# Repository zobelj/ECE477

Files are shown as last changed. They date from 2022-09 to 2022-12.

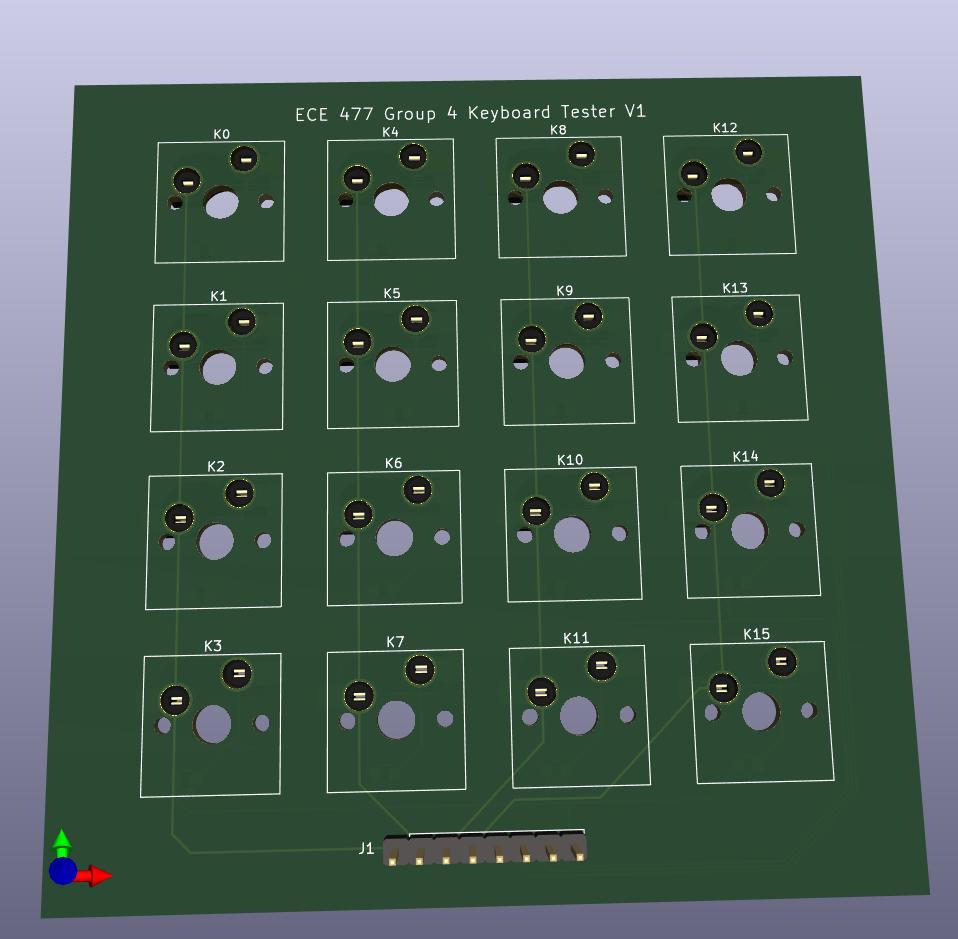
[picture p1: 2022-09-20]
KBT1/renders/KBT1-1.jpg

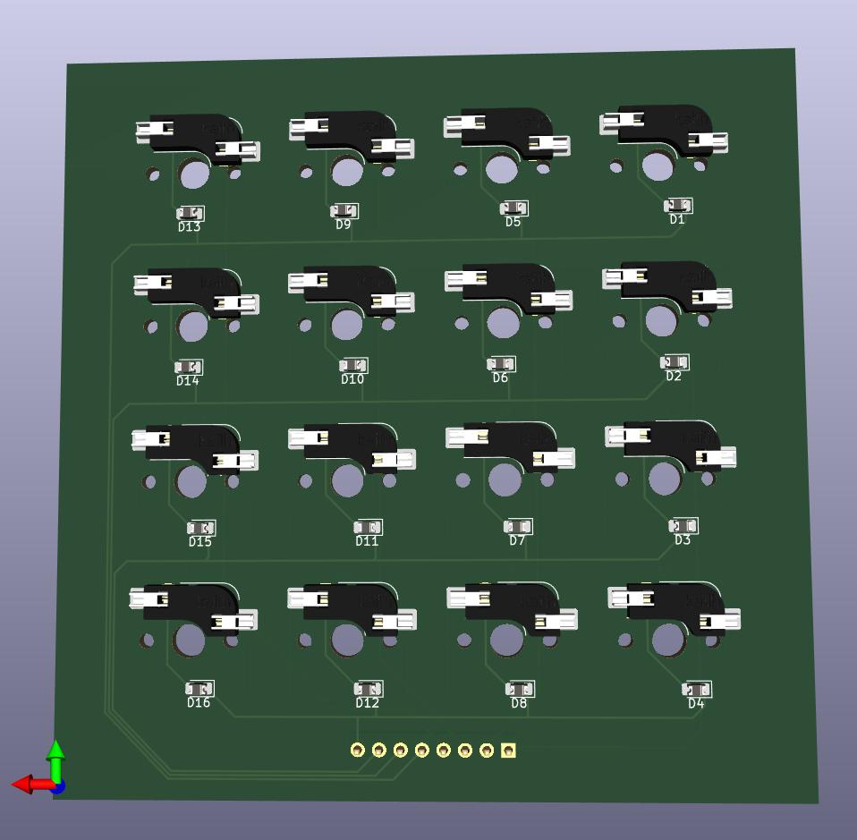
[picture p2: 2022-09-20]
KBT1/renders/KBT1-2.jpg

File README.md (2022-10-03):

# Split USB Keyboard
ECE477 Team 4 github

## Reset source code to work as keyboard
1. Make changes to .ioc file and save it
2. Build the code
3. Delete the Middlewares folder
4. Unzip Middlewares KEYBOARD SETUP.zip and rename the folder to Middlewares (Keep the ziped file here for future use)
5. Build the code (there will likely be errors, if so proceed to step 6)
6. Navigate to Drivers>STM32F4xx_HAL_DRIVER>Src in this directory there will be duplicate files that look like this `...cortex.c` and `...cortext 2.c` or `...cortex 3.c` to fix this delete all of the files that have a number at the end of the file name. This can easily be done in the console/terminal with `rm *2.c` or `rm *3.c`

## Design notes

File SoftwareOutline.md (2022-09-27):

# Software Outline

This file is meant to serve as a general outline of the software running on the microcontrollers.

In its current state, only an outline of the keyboard input is included but will be updated to describe LCD functions, etc.

NOTE: When wiring the 4x4 test PCB, the columns are the left 4 pins and the rows are the right 4 pins. The columns should be pulled high.

## Keyboard Input

---

### Preprocessing Overview
Some global variables will be set up before the keyboard is ready to use.

Tasks:
- set `rows` to be outputs, initialize all to low (eg. PA0-PA3)
- set `cols` to be inputs (eg. PA4-PA7)
- setup timer interrupt
- setup pins
- ...

Global variables:
- `queue` : array that holds the keypresses to be sent 
- `queue_index` : the index of the next available space in the queue
- ...

---

### Timer Interrupt Overview
- A timer `TIMx` will be set to interrupt the process at a  frequency of 10kHz (?)
- `TIMx_IRQHandler()` will do the following:
  - Acknowledge the interrupt
  - Check for columns that are activated (`get_cols()`)
  - Update the `queue` variable with any keys that were pressed between `send_data()` calls
  - Change the row currently set (`set_rows()`)
- `send_data()` sends the queue to the host PC at a frequency of 1000Hz (polling rate)
  - resets `queue`, prepares for next packet
- 

---

### Functions to Implement
- `get_key()`
  - waits for the interrupt to update the queue
  - converts the row-column value in queue to a key (switch case)
  - returns the key being pressed
  - *Is this useful for our keyboard? I don't think we should have a `get_key()` function*
  - *This funcitonality should probably exist in the `send_data()` function or in `main()`*
- `TIMx_IRQHandler()`
  - runs `get_cols()`
  - figures out what key is being pressed
  - runs `set_rows()` to change active row for the next interrupt
- `TIMx_setup()`
  - initializes the timer frequency
  - enables the timer
- `setup_pins()`
  - initialize pins for rows and columns
  - maybe initialize other necessary pins (LCDs, LEDs, etc.)
- `get_cols()`
  - returns the values of the column inputs as a 4-bit number
  - eg. `0010` indicates that columns 0, 2, and 3 are low and column 1 is high
- `set_rows()`
  - one active row at a time
  - changes the active row to the next row
  - eg. `0001` -> `0010` indicates the active row is changed from row 0 to row 1
- `update_queue`
  - add new keypresses to the end of the queue
  - these keypresses will be included in the next packet sent to the PC
- `send_data()`
  - send the queue to the host PC
  - clear the queue, reset the queue index

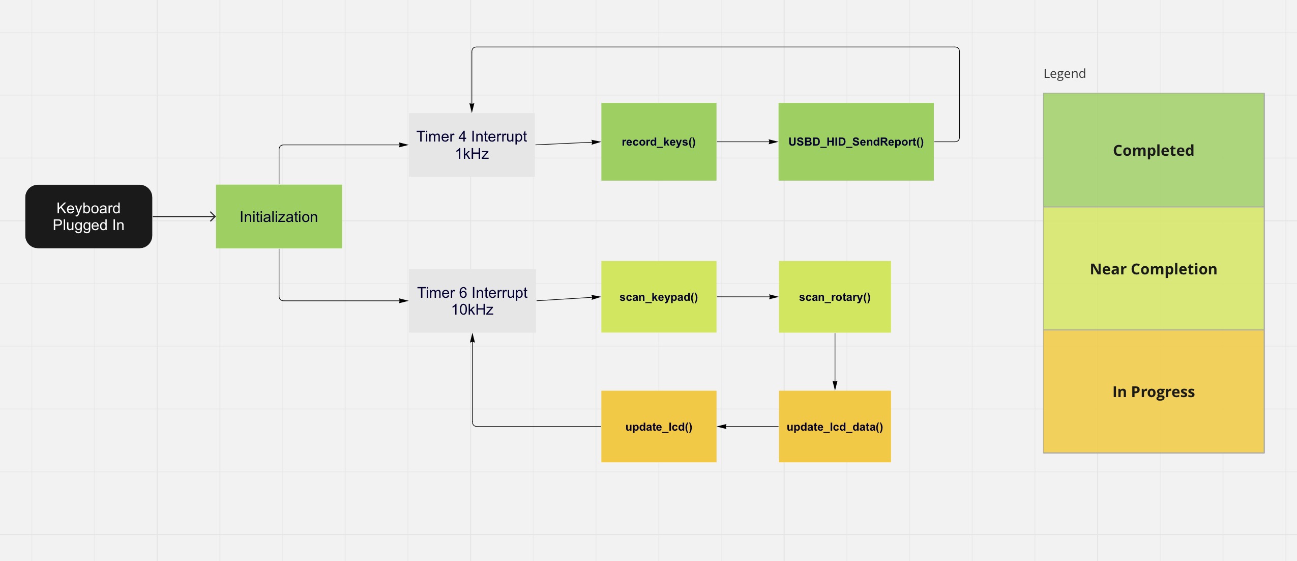
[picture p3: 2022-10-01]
Software_Flowchart.jpg

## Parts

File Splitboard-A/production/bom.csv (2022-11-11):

Designator | Footprint | Quantity | Value | LCSC Part #
C1, C2 | C_0805_2012Metric | 2 | 2u2
C10, C11, C12, C13, C14, C15, C18, C20, C21, C5, C7, C8, C9 | C_0805_2012Metric | 13 | 100nF
C16, C17 | C_0805_2012Metric | 2 | .01uF
C19, C6 | C_0805_2012Metric | 2 | 10uf
C3, C4 | C_0805_2012Metric | 2 | 10u
D1, D10, D11, D12, D13, D14, D15, D16, D17, D18, D19, D2, D20, D21, D22, D23, D24, D25, D26, D27, D28, D29, D3, D30, D31, D32, D33, D34, D35, D36, D37, D38, D4, D5, D6, D7, D8, D9 | D_SOD-123 | 38 | D
D39, D40, D41 | D_SOD-123 | 3 | D_Schottky
FB1 | R_0805_2012Metric | 1 | 100 @ 100 MHz
H1, H2, H3, H4 | MountingHole_2.7mm | 4 | MountingHole
J1 | USB_C_Receptacle_Amphenol_12401548E4-2A | 1 | USB_C_Receptacle_USB2.0
J2 | USB_C_Receptacle_Amphenol_12401548E4-2A | 1 | USB_C_Receptacle
J3 | PinHeader_1x06_P2.54mm_Horizontal | 1 | Conn_01x06
K1, K10, K11, K12, K13, K14, K15, K16, K17, K18, K19, K2, K20, K21, K22, K23, K24, K25, K26, K27, K28, K29, K3, K30, K31, K32, K33, K34, K35, K36, K37, K38, K4, K5, K6, K7, K8, K9 | SW_Hotswap_Kailh_MX_plated | 38 | KEYSW
R1, R2 | R_0805_2012Metric | 2 | 5K1
R10, R11, R12, R13, R14, R15, R4, R5, R6, R7, R8, R9 | R_0805_2012Metric | 12 | 10k
R16, R17, R18, R19, R20, R21, R22, R23, R24, R25, R26, R27, R28, R29, R3, R30, R31, R32, R33, R34, R35, R36, R37 | R_0805_2012Metric | 23 | 20
R38, R39 | R_0805_2012Metric | 2 | 4k7
SW1 | RotaryEncoder_Alps_EC11E-Switch_Vertical_H20mm | 1 | RotaryEncoder
SW2 | SW_PUSH_6mm | 1 | SW_Push
U1 | SIT2024BA-S2-33E-8.000000G | 1 | SIT2024BA-S2-33E-8.000000G
U2 | CR2013-MI2120 | 1 | CR2013-MI2120
U3 | LQFP-100_14x14mm_P0.5mm | 1 | STM32F407VGTx
U4 | SOT-223-3_TabPin2 | 1 | AMS1117-3.3
U5 | USBUF02W6 | 1 | USBUF02W6

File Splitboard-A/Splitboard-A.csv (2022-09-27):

Source: | /home/smol/Projects/ECE477/Splitboard-A/Splitboard-A.kicad_sch
Date: | Thu 22 Sep 2022 04:38:41 PM EDT
Tool: | Eeschema 6.0.7-f9a2dced07~116~ubuntu20.04.1
Generator: | /usr/share/kicad/plugins/bom_csv_grouped_by_value.py
Component Count: | 96
Individual Components:
Item | Qty | Reference(s) | Value | LibPart | Footprint | Datasheet
 |  | C2 | 10u | Device:C | Capacitor_SMD:C_0805_2012Metric | ~
 |  | C3 | 0.1uF | Device:C | Resistor_SMD:R_0805_2012Metric | ~
 |  | C4 | 10u | Device:C | Capacitor_SMD:C_0805_2012Metric | ~
 |  | D1 | D | KBT1-rescue:D-Device | Diode_SMD:D_SOD-123
 |  | D2 | D | KBT1-rescue:D-Device | Diode_SMD:D_SOD-123
 |  | D3 | D | KBT1-rescue:D-Device | Diode_SMD:D_SOD-123
 |  | D4 | D | KBT1-rescue:D-Device | Diode_SMD:D_SOD-123
 |  | D5 | D | KBT1-rescue:D-Device | Diode_SMD:D_SOD-123
 |  | D6 | D | KBT1-rescue:D-Device | Diode_SMD:D_SOD-123
 |  | D7 | D | KBT1-rescue:D-Device | Diode_SMD:D_SOD-123
 |  | D8 | D | KBT1-rescue:D-Device | Diode_SMD:D_SOD-123
 |  | D9 | D | KBT1-rescue:D-Device | Diode_SMD:D_SOD-123
 |  | D10 | D | KBT1-rescue:D-Device | Diode_SMD:D_SOD-123
 |  | D11 | D | KBT1-rescue:D-Device | Diode_SMD:D_SOD-123
 |  | D12 | D | KBT1-rescue:D-Device | Diode_SMD:D_SOD-123
 |  | D13 | D | KBT1-rescue:D-Device | Diode_SMD:D_SOD-123
 |  | D14 | D | KBT1-rescue:D-Device | Diode_SMD:D_SOD-123
 |  | D15 | D | KBT1-rescue:D-Device | Diode_SMD:D_SOD-123
 |  | D16 | D | KBT1-rescue:D-Device | Diode_SMD:D_SOD-123
 |  | D17 | D | KBT1-rescue:D-Device | Diode_SMD:D_SOD-123
 |  | D18 | D | KBT1-rescue:D-Device | Diode_SMD:D_SOD-123
 |  | D19 | D | KBT1-rescue:D-Device | Diode_SMD:D_SOD-123
 |  | D20 | D | KBT1-rescue:D-Device | Diode_SMD:D_SOD-123
 |  | D21 | D | KBT1-rescue:D-Device | Diode_SMD:D_SOD-123
 |  | D22 | D | KBT1-rescue:D-Device | Diode_SMD:D_SOD-123
 |  | D23 | D | KBT1-rescue:D-Device | Diode_SMD:D_SOD-123
 |  | D24 | D | KBT1-rescue:D-Device | Diode_SMD:D_SOD-123
 |  | D25 | D | KBT1-rescue:D-Device | Diode_SMD:D_SOD-123
 |  | D26 | D | KBT1-rescue:D-Device | Diode_SMD:D_SOD-123
 |  | D27 | D | KBT1-rescue:D-Device | Diode_SMD:D_SOD-123
 |  | D28 | D | KBT1-rescue:D-Device | Diode_SMD:D_SOD-123
 |  | D29 | D | KBT1-rescue:D-Device | Diode_SMD:D_SOD-123
 |  | D30 | D | KBT1-rescue:D-Device | Diode_SMD:D_SOD-123
 |  | D31 | D | KBT1-rescue:D-Device | Diode_SMD:D_SOD-123
 |  | D32 | D | KBT1-rescue:D-Device | Diode_SMD:D_SOD-123
 |  | D33 | D | KBT1-rescue:D-Device | Diode_SMD:D_SOD-123
 |  | D34 | D | KBT1-rescue:D-Device | Diode_SMD:D_SOD-123
 |  | D35 | D | KBT1-rescue:D-Device | Diode_SMD:D_SOD-123
 |  | D36 | D | KBT1-rescue:D-Device | Diode_SMD:D_SOD-123
 |  | D37 | D | KBT1-rescue:D-Device | Diode_SMD:D_SOD-123
 |  | D38 | D | KBT1-rescue:D-Device | Diode_SMD:D_SOD-123
 |  | D39 | D_Schottky | Device:D_Schottky |  | ~
 |  | D40 | D_Schottky | Device:D_Schottky |  | ~
 |  | D41 | D_Schottky | Device:D_Schottky |  | ~
 |  | F1 | 500mA | Device:Fuse |  | ~
 |  | FB1 | 100 @ 100 MHz | Device:FerriteBead |  | ~
 |  | H1 | MountingHole | Mechanical:MountingHole | MountingHole:MountingHole_2.7mm | ~
 |  | H2 | MountingHole | Mechanical:MountingHole | MountingHole:MountingHole_2.7mm | ~
 |  | H3 | MountingHole | Mechanical:MountingHole | MountingHole:MountingHole_2.7mm | ~
 |  | H4 | MountingHole | Mechanical:MountingHole | MountingHole:MountingHole_2.7mm | ~
 |  | J1 | USB_C_Receptacle | Connector:USB_C_Receptacle | Connector_USB:USB_C_Receptacle_Amphenol_12401548E4-2A_CircularHoles | https://www.usb.org/sites/default/files/documents/usb_type-c.zip
 |  | J2 | USB_C_Receptacle_USB2.0 | Connector:USB_C_Receptacle_USB2.0 | Connector_USB:USB_C_Receptacle_Amphenol_12401548E4-2A_CircularHoles | https://www.usb.org/sites/default/files/documents/usb_type-c.zip
 |  | K1 | KEYSW | KBT1-rescue:KEYSW-keyboard_parts | 6:SW_Hotswap_Kailh_MX_plated
 |  | K2 | KEYSW | KBT1-rescue:KEYSW-keyboard_parts | 6:SW_Hotswap_Kailh_MX_plated
 |  | K3 | KEYSW | KBT1-rescue:KEYSW-keyboard_parts | 6:SW_Hotswap_Kailh_MX_plated
 |  | K4 | KEYSW | KBT1-rescue:KEYSW-keyboard_parts | 6:SW_Hotswap_Kailh_MX_plated
 |  | K5 | KEYSW | KBT1-rescue:KEYSW-keyboard_parts | 6:SW_Hotswap_Kailh_MX_plated
 |  | K6 | KEYSW | KBT1-rescue:KEYSW-keyboard_parts | 6:SW_Hotswap_Kailh_MX_plated
 |  | K7 | KEYSW | KBT1-rescue:KEYSW-keyboard_parts | 6:SW_Hotswap_Kailh_MX_plated
 |  | K8 | KEYSW | KBT1-rescue:KEYSW-keyboard_parts | 6:SW_Hotswap_Kailh_MX_plated
 |  | K9 | KEYSW | KBT1-rescue:KEYSW-keyboard_parts | 6:SW_Hotswap_Kailh_MX_plated
 |  | K10 | KEYSW | KBT1-rescue:KEYSW-keyboard_parts | 6:SW_Hotswap_Kailh_MX_plated
 |  | K11 | KEYSW | KBT1-rescue:KEYSW-keyboard_parts | 6:SW_Hotswap_Kailh_MX_plated
 |  | K12 | KEYSW | KBT1-rescue:KEYSW-keyboard_parts | 6:SW_Hotswap_Kailh_MX_plated
 |  | K13 | KEYSW | KBT1-rescue:KEYSW-keyboard_parts | 6:SW_Hotswap_Kailh_MX_plated
 |  | K14 | KEYSW | KBT1-rescue:KEYSW-keyboard_parts | 6:SW_Hotswap_Kailh_MX_plated
 |  | K15 | KEYSW | KBT1-rescue:KEYSW-keyboard_parts | 6:SW_Hotswap_Kailh_MX_plated
 |  | K16 | KEYSW | KBT1-rescue:KEYSW-keyboard_parts | 6:SW_Hotswap_Kailh_MX_plated
 |  | K17 | KEYSW | KBT1-rescue:KEYSW-keyboard_parts | 6:SW_Hotswap_Kailh_MX_plated
 |  | K18 | KEYSW | KBT1-rescue:KEYSW-keyboard_parts | 6:SW_Hotswap_Kailh_MX_plated
 |  | K19 | KEYSW | KBT1-rescue:KEYSW-keyboard_parts | 6:SW_Hotswap_Kailh_MX_plated
 |  | K20 | KEYSW | KBT1-rescue:KEYSW-keyboard_parts | 6:SW_Hotswap_Kailh_MX_plated
 |  | K21 | KEYSW | KBT1-rescue:KEYSW-keyboard_parts | 6:SW_Hotswap_Kailh_MX_plated
 |  | K22 | KEYSW | KBT1-rescue:KEYSW-keyboard_parts | 6:SW_Hotswap_Kailh_MX_plated
 |  | K23 | KEYSW | KBT1-rescue:KEYSW-keyboard_parts | 6:SW_Hotswap_Kailh_MX_plated
 |  | K24 | KEYSW | KBT1-rescue:KEYSW-keyboard_parts | 6:SW_Hotswap_Kailh_MX_plated
 |  | K25 | KEYSW | KBT1-rescue:KEYSW-keyboard_parts | 6:SW_Hotswap_Kailh_MX_plated
 |  | K26 | KEYSW | KBT1-rescue:KEYSW-keyboard_parts | 6:SW_Hotswap_Kailh_MX_plated
 |  | K27 | KEYSW | KBT1-rescue:KEYSW-keyboard_parts | 6:SW_Hotswap_Kailh_MX_plated
 |  | K28 | KEYSW | KBT1-rescue:KEYSW-keyboard_parts | 6:SW_Hotswap_Kailh_MX_plated
 |  | K29 | KEYSW | KBT1-rescue:KEYSW-keyboard_parts | 6:SW_Hotswap_Kailh_MX_plated
 |  | K30 | KEYSW | KBT1-rescue:KEYSW-keyboard_parts | 6:SW_Hotswap_Kailh_MX_plated
 |  | K31 | KEYSW | KBT1-rescue:KEYSW-keyboard_parts | 6:SW_Hotswap_Kailh_MX_plated
 |  | K32 | KEYSW | KBT1-rescue:KEYSW-keyboard_parts | 6:SW_Hotswap_Kailh_MX_plated
 |  | K33 | KEYSW | KBT1-rescue:KEYSW-keyboard_parts | 6:SW_Hotswap_Kailh_MX_plated
 |  | K34 | KEYSW | KBT1-rescue:KEYSW-keyboard_parts | 6:SW_Hotswap_Kailh_MX_plated
 |  | K35 | KEYSW | KBT1-rescue:KEYSW-keyboard_parts | 6:SW_Hotswap_Kailh_MX_plated
 |  | K36 | KEYSW | KBT1-rescue:KEYSW-keyboard_parts | 6:SW_Hotswap_Kailh_MX_plated
 |  | K37 | KEYSW | KBT1-rescue:KEYSW-keyboard_parts | 6:SW_Hotswap_Kailh_MX_plated
 |  | K38 | KEYSW | KBT1-rescue:KEYSW-keyboard_parts | 6:SW_Hotswap_Kailh_MX_plated
 |  | R3 | 10K | Device:R | Resistor_SMD:R_0805_2012Metric | ~
 |  | R4 | 100K | Device:R | Resistor_SMD:R_0805_2012Metric | ~
 |  | SW1 | RotaryEncoder | Device:RotaryEncoder | Rotary_Encoder:RotaryEncoder_Alps_EC12E_Vertical_H20mm | ~
 |  | U1 | STM32F407VGTx | MCU_ST_STM32F4:STM32F407VGTx | Package_QFP:LQFP-100_14x14mm_P0.5mm | http://www.st.com/st-web-ui/static/active/en/resource/technical/document/datasheet/DM00037051.pdf
 |  | U2 | AMS1117-3.3 | Regulator_Linear:AMS1117-3.3 | Package_TO_SOT_SMD:SOT-223-3_TabPin2 | http://www.advanced-monolithic.com/pdf/ds1117.pdf
 |  | U3 | CR2013-MI2120 | Driver_Display:CR2013-MI2120 | Display:CR2013-MI2120 | http://pan.baidu.com/s/11Y990
Collated Components:
Item | Qty | Reference(s) | Value | LibPart | Footprint | Datasheet
1 | 2 | C2, C4 | 10u | Device:C | Capacitor_SMD:C_0805_2012Metric | ~
2 | 1 | C3 | 0.1uF | Device:C | Resistor_SMD:R_0805_2012Metric | ~
3 | 38 | D1, D2, D3, D4, D5, D6, D7, D8, D9, D10, D11, D12, D13, D14, D15, D16, D17, D18, D19, D20, D21, D22, D23, D24, D25, D26, D27, D28, D29, D30, D31, D32, D33, D34, D35, D36, D37, D38 | D | KBT1-rescue:D-Device | Diode_SMD:D_SOD-123
4 | 3 | D39, D40, D41 | D_Schottky | Device:D_Schottky |  | ~
5 | 1 | F1 | 500mA | Device:Fuse |  | ~
6 | 1 | FB1 | 100 @ 100 MHz | Device:FerriteBead |  | ~
7 | 4 | H1, H2, H3, H4 | MountingHole | Mechanical:MountingHole | MountingHole:MountingHole_2.7mm | ~
8 | 1 | J1 | USB_C_Receptacle | Connector:USB_C_Receptacle | Connector_USB:USB_C_Receptacle_Amphenol_12401548E4-2A_CircularHoles | https://www.usb.org/sites/default/files/documents/usb_type-c.zip
9 | 1 | J2 | USB_C_Receptacle_USB2.0 | Connector:USB_C_Receptacle_USB2.0 | Connector_USB:USB_C_Receptacle_Amphenol_12401548E4-2A_CircularHoles | https://www.usb.org/sites/default/files/documents/usb_type-c.zip
10 | 38 | K1, K2, K3, K4, K5, K6, K7, K8, K9, K10, K11, K12, K13, K14, K15, K16, K17, K18, K19, K20, K21, K22, K23, K24, K25, K26, K27, K28, K29, K30, K31, K32, K33, K34, K35, K36, K37, K38 | KEYSW | KBT1-rescue:KEYSW-keyboard_parts | 6:SW_Hotswap_Kailh_MX_plated
11 | 1 | R3 | 10K | Device:R | Resistor_SMD:R_0805_2012Metric | ~
12 | 1 | R4 | 100K | Device:R | Resistor_SMD:R_0805_2012Metric | ~
13 | 1 | SW1 | RotaryEncoder | Device:RotaryEncoder | Rotary_Encoder:RotaryEncoder_Alps_EC12E_Vertical_H20mm | ~
14 | 1 | U1 | STM32F407VGTx | MCU_ST_STM32F4:STM32F407VGTx | Package_QFP:LQFP-100_14x14mm_P0.5mm | http://www.st.com/st-web-ui/static/active/en/resource/technical/document/datasheet/DM00037051.pdf
15 | 1 | U2 | AMS1117-3.3 | Regulator_Linear:AMS1117-3.3 | Package_TO_SOT_SMD:SOT-223-3_TabPin2 | http://www.advanced-monolithic.com/pdf/ds1117.pdf
16 | 1 | U3 | CR2013-MI2120 | Driver_Display:CR2013-MI2120 | Display:CR2013-MI2120 | http://pan.baidu.com/s/11Y990

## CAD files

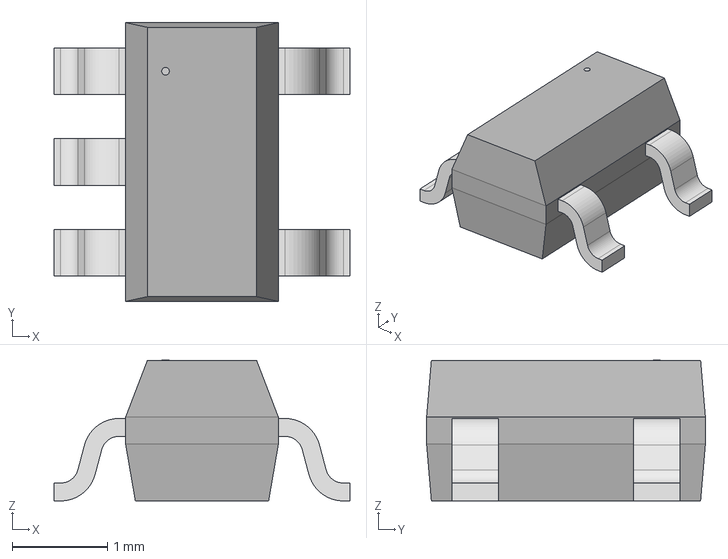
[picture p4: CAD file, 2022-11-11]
imported libraries/SIT2024BA/2022-10-06_01-32-12/STEP/SOT_SiT1630-S_SIT.step
3.10 x 2.92 x 1.48 mm

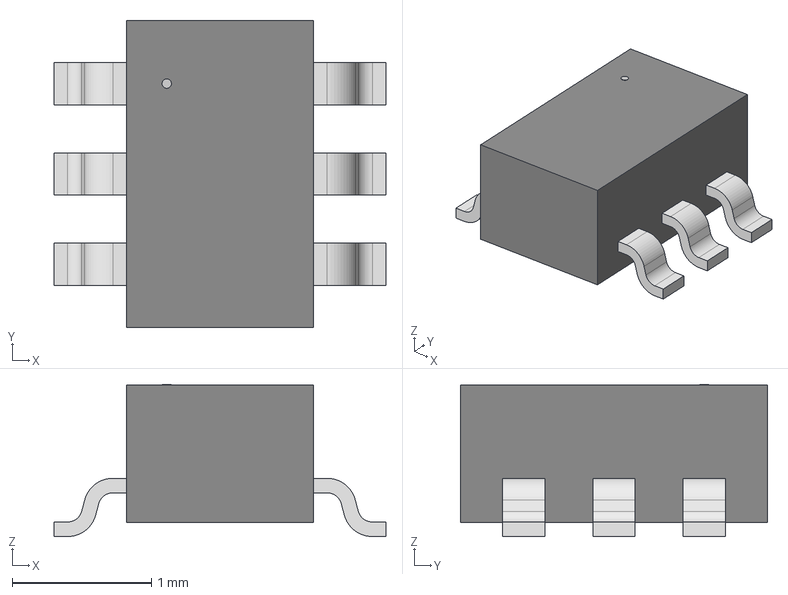
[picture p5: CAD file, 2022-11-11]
imported libraries/USBUF02W6/2022-10-05_22-36-43/STEP/SOTT323-6L_STM.step
2.39 x 2.21 x 1.09 mm

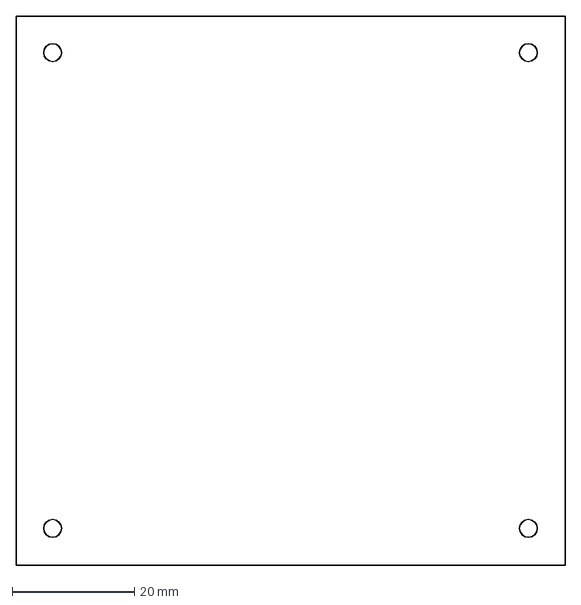
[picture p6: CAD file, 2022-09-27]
KBT1/KBT1 Bottom Plate.dxf
90.0 x 90.0 mm

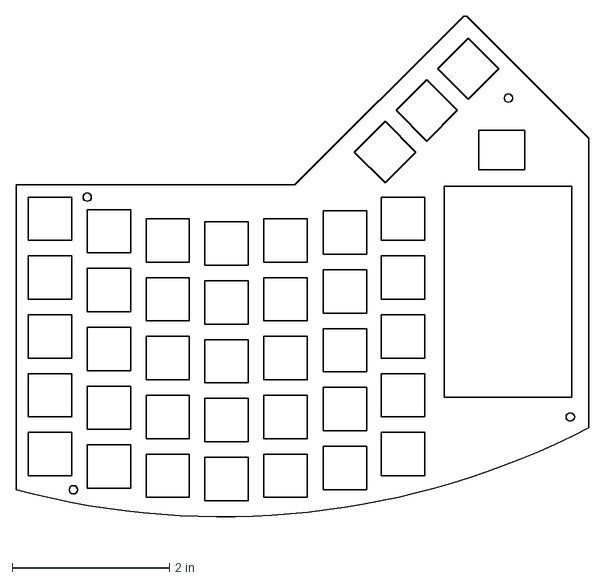
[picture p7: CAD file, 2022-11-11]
Split Keyboard Acrylic Plates/Side B Top.dxf
7.28 x 6.68 in

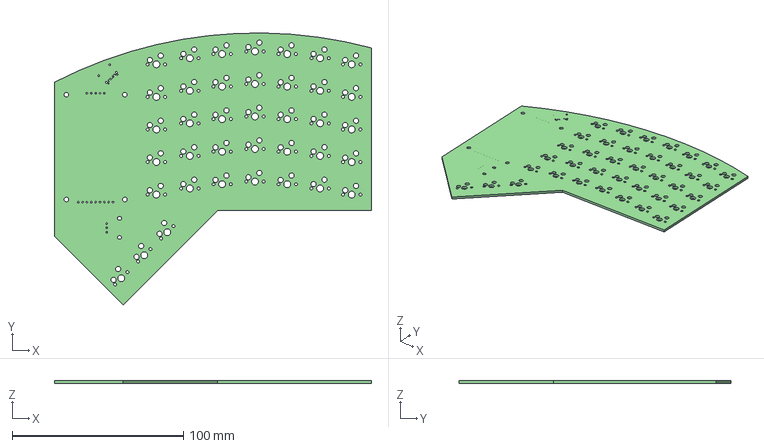
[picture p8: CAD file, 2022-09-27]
Splitboard-B/Splitboard-B.step
185.0 x 158.7 x 1.60 mm

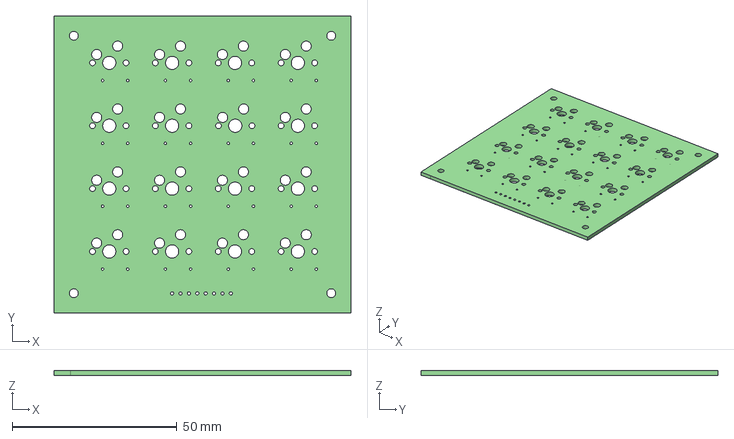
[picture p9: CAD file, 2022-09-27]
KBT1/KBT1.step
90.0 x 90.0 x 1.60 mm

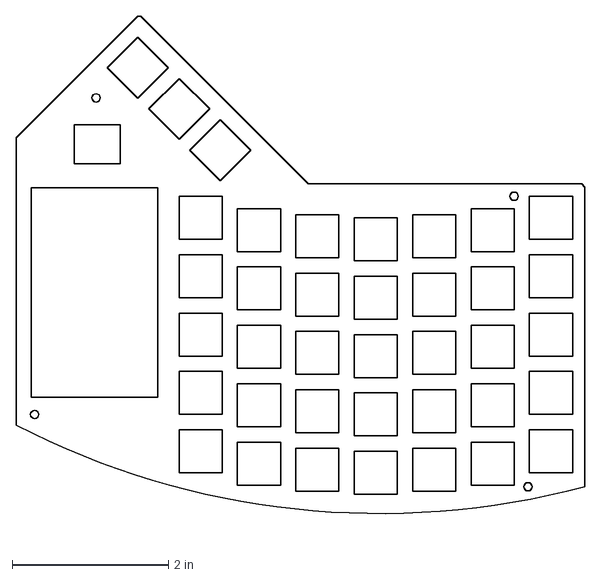
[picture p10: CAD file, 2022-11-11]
Split Keyboard Acrylic Plates/Side A Top.dxf
7.28 x 6.68 in

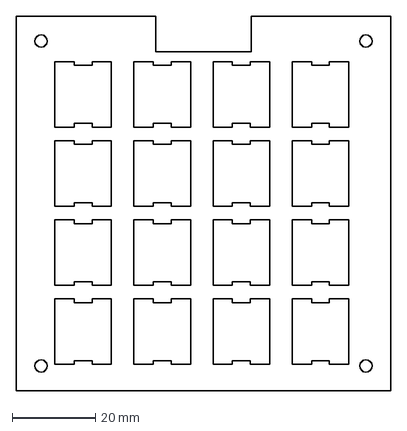
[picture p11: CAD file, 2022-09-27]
KBT1/KBT1 Base Plate.dxf
90.0 x 90.0 mm

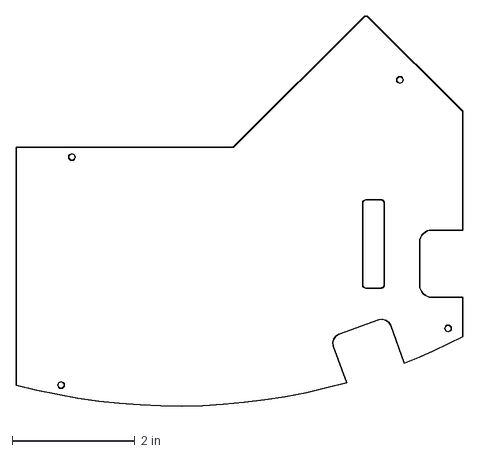
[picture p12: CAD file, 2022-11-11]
Split Keyboard Acrylic Plates/Side B Bottom.dxf
7.28 x 6.50 in

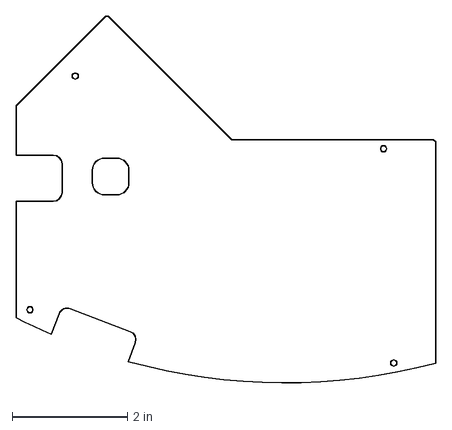
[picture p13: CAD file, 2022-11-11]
Split Keyboard Acrylic Plates/Side A Bottom.dxf
7.28 x 6.49 in

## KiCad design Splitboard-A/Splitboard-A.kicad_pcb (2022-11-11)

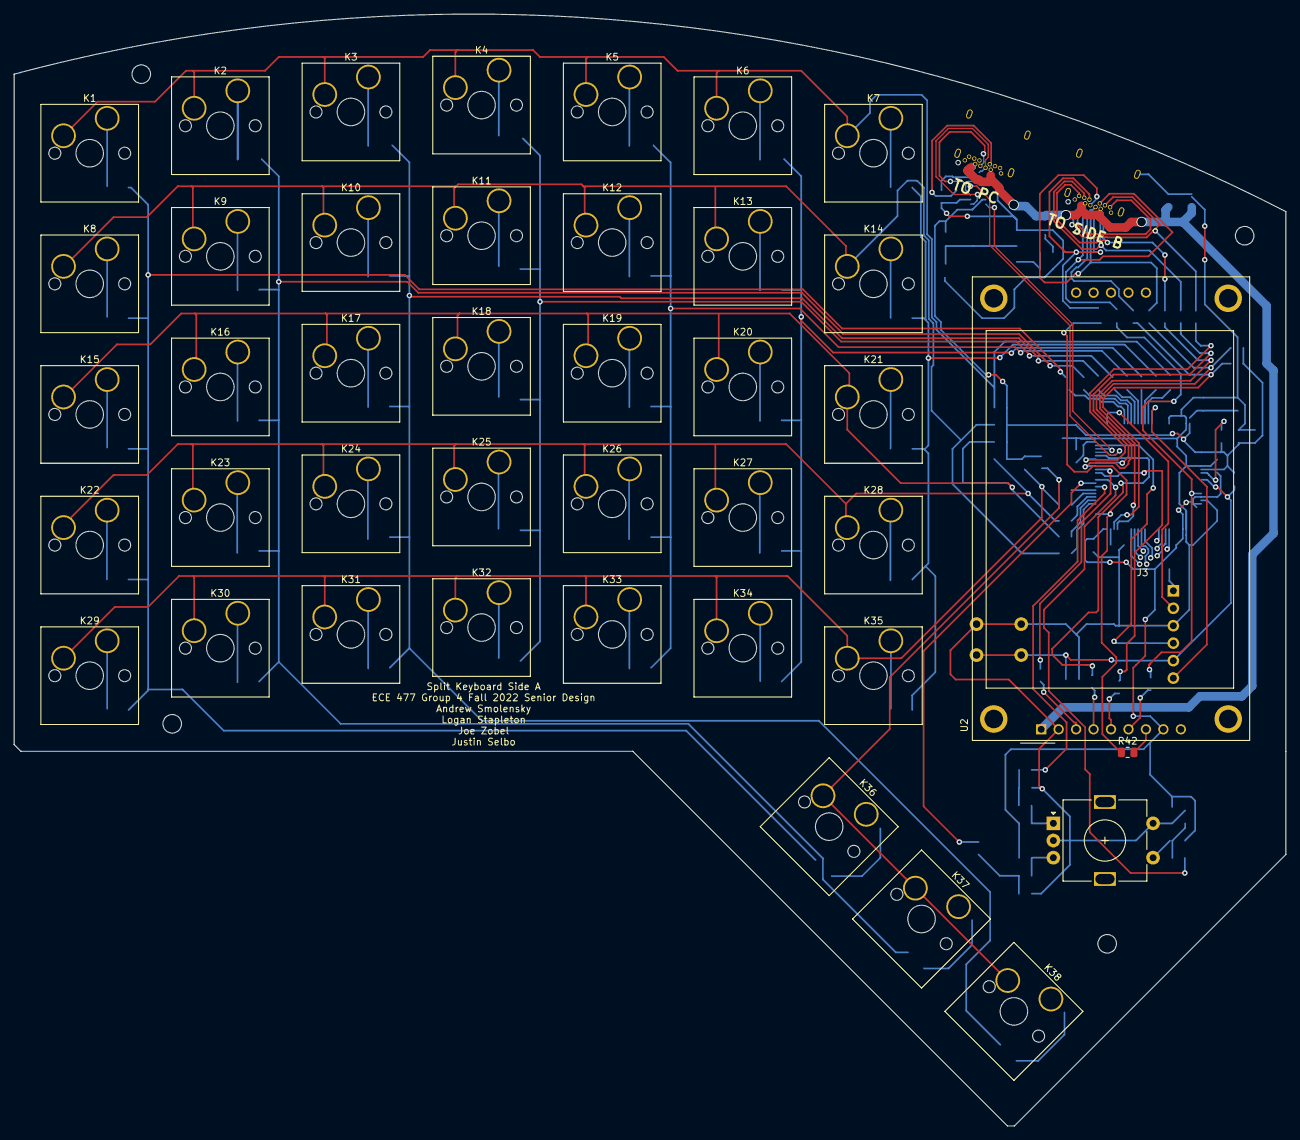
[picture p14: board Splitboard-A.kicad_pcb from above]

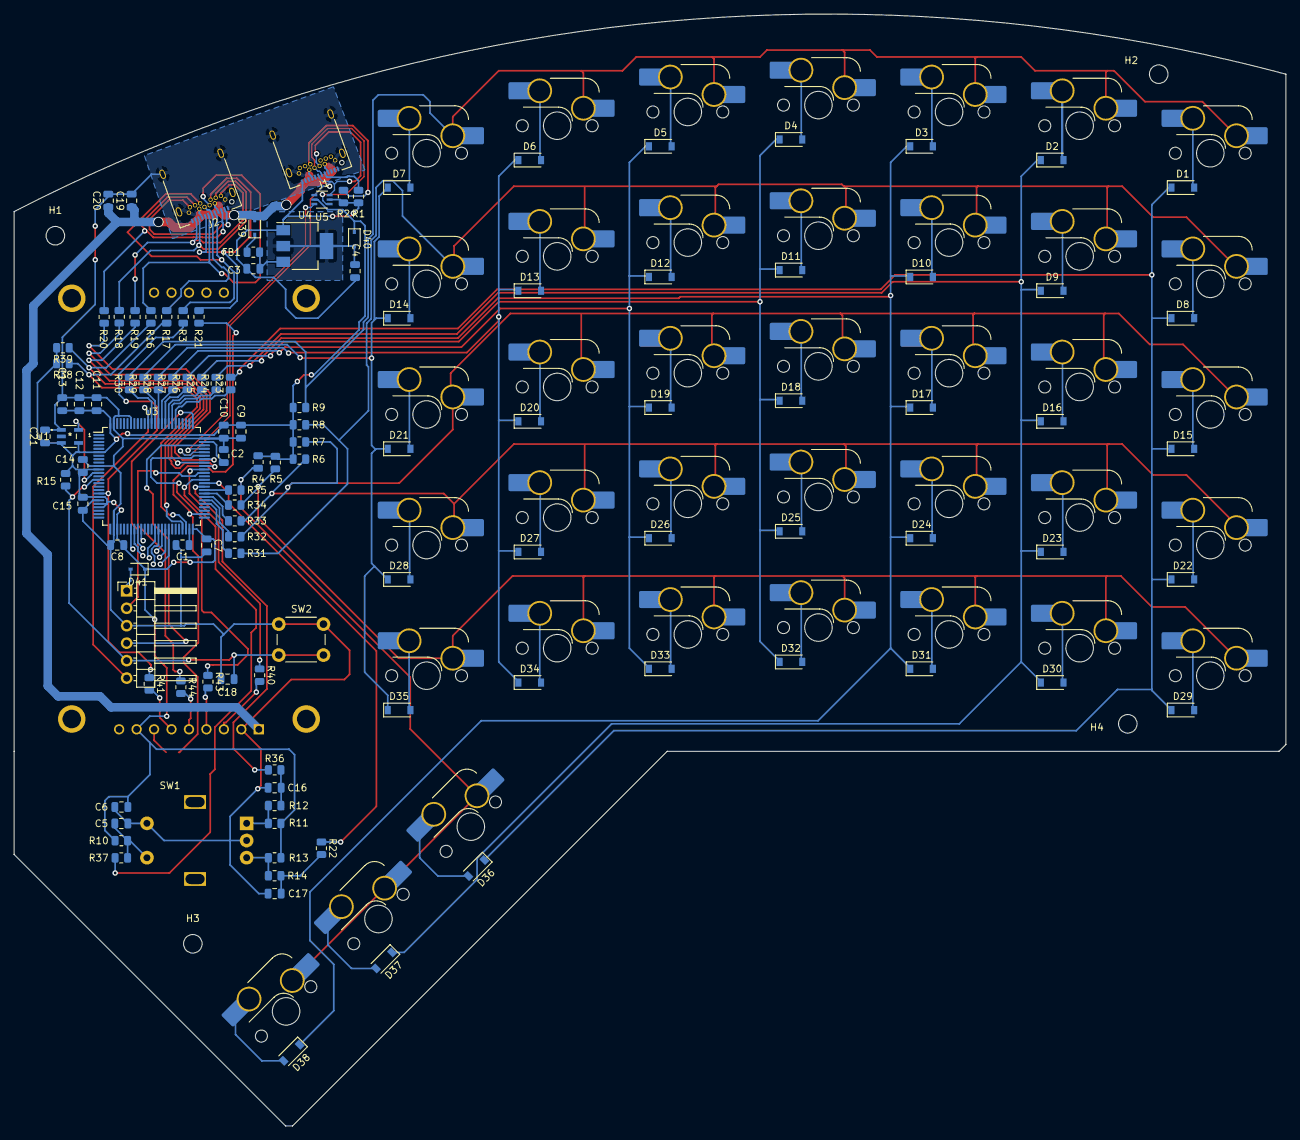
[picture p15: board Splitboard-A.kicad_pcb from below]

Board: 2 copper layers, 185.0 x 161.7 mm, 159 parts (118 on the bottom side), 115 nets.

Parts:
C1, C2: 2u2; C_0805_2012Metric
C3, C4: 10u; C_0805_2012Metric
C5, C7, C8, C9, C10, C11, C12, C13, C14, C15, C18, C20, C21: 100nF; C_0805_2012Metric
C6, C19: 10uf; C_0805_2012Metric
C16, C17: .01uF; C_0805_2012Metric
D1, D2, D3, D4, D5, D6, D7, D8, D9, D10, D11, D12, D13, D14, D15, D16, D17, D18, D19, D20, D21, D22, D23, D24, D25, D26, D27, D28, D29, D30, D31, D32, D33, D34, D35, D36, D37, D38: D; D_SOD-123
D39, D40, D41: D_Schottky; D_SOD-323
FB1: 100 @ 100 MHz; R_0805_2012Metric
H1, H2, H3, H4: MountingHole; MountingHole_2.7mm
J1: USB_C_Receptacle_USB2.0; USB_C_Receptacle_Amphenol_12401548E4-2A
J2: USB_C_Receptacle; USB_C_Receptacle_Amphenol_12401548E4-2A
J3: Conn_01x06; PinHeader_1x06_P2.54mm_Horizontal
K1, K2, K3, K4, K5, K6, K7, K8, K9, K10, K11, K12, K13, K14, K15, K16, K17, K18, K19, K20, K21, K22, K23, K24, K25, K26, K27, K28, K29, K30, K31, K32, K33, K34, K35, K36, K37, K38: KEYSW; SW_Hotswap_Kailh_MX_plated
R1, R2: 5K1; R_0805_2012Metric
R3, R16, R17, R18, R19, R20, R21, R22, R23, R24, R25, R26, R27, R28, R29, R30, R31, R32, R33, R34, R35, R36, R37, R40, R41, R42, R43, R44: 20; R_0805_2012Metric
R4, R5, R6, R7, R8, R9, R10, R11, R12, R13, R14: 10k; R_0805_2012Metric
R15: 10K; R_0805_2012Metric
R38, R39: 4k7; R_0805_2012Metric
SW1: RotaryEncoder; RotaryEncoder_Alps_EC11E-Switch_Vertical_H20mm
SW2: SW_Push; SW_PUSH_6mm
U1: SIT2024BA-S2-33E-8.000000G
U2: CR2013-MI2120
U3: STM32F407VGTx; LQFP-100_14x14mm_P0.5mm
U4: AMS1117-3.3; SOT-223-3_TabPin2
U5: USBUF02W6

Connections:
+3.3V: C6.1, C7.1, C8.1, C9.1, C10.1, C11.1, C12.1, C13.1, C14.1, C15.1, C21.1, D40.1 (K), D41.1 (K), R4.2, R5.2, R6.2, R7.2, R8.2, R9.2, R10.2, R11.1, R13.1, R15.1, R38.2, R39.2, U1.3 (OE/NC), U1.4 (VDD), U2.8 (LED), U3.6 (VBAT), U3.11 (VDD), U3.19 (VDD), U3.21 (VREF+), U3.22 (VDDA), U3.28 (VDD), U3.50 (VDD), U3.75 (VDD), U3.100 (VDD), U5.5 (VDD)
/ENC_A: C16.1, R12.1, R36.2
/ENC_B: C17.2, R14.2, R22.2
/ENC_SW: C5.2, R10.1, R37.2, SW1.S1
/LCD1_CS: R40.1, U3.65 (PC8)
/LCD1_DC: R44.1, U3.64 (PC7)
/LCD1_RST: R43.1, U3.69 (PA10)
/LCD2_CS: R18.1, U3.67 (PA8)
/LCD2_DC: R19.1, U3.66 (PC9)
/LCD2_RST: R20.1, U3.68 (PA9)
/MOSI: R3.1, R41.1, U3.18 (PC3)
/NRST: C18.2, J3.5, R15.2, SW2.2, U3.14 (NRST)
/RCC_OSC_IN: U1.5 (OUT), U3.12 (PH0)
/SCK: R21.1, R42.1, U3.52 (PB13)
/SCL: R16.1, R39.1, U3.47 (PB10)
/SDA: R17.1, R38.1, U3.48 (PB11)
/SWCLK: J3.2, U3.76 (PA14)
/SWDIO: J3.4, U3.72 (PA13)
/SWO: J3.6, U3.89 (PB3)
/USB_CONN_D+: J1.A6 (D+), J1.B6 (D+), U5.1 (D1)
/USB_CONN_D-: J1.A7 (D-), J1.B7 (D-), U5.3 (D2)
/USB_D+: U3.71 (PA12), U5.6 (D4)
/USB_D-: U3.70 (PA11), U5.4 (D3)
/col0: K1.1, K2.1, K3.1, K4.1, K5.1, K6.1, K7.1, R9.1, R30.2
/col1: K8.1, K9.1, K10.1, K11.1, K12.1, K13.1, K14.1, R8.1, R31.2
/col2: K15.1, K16.1, K17.1, K18.1, K19.1, K20.1, K21.1, R7.1, R32.2
/col3: K22.1, K23.1, K24.1, K25.1, K26.1, K27.1, K28.1, R6.1, R33.2
/col4: K29.1, K30.1, K31.1, K32.1, K33.1, K34.1, K35.1, R5.1, R34.2
/col5: K36.1, K37.1, K38.1, R4.1, R35.2
/row0: D1.1 (K), D8.1 (K), D15.1 (K), D22.1 (K), D29.1 (K), D36.1 (K), R23.2
/row1: D2.1 (K), D9.1 (K), D16.1 (K), D23.1 (K), D30.1 (K), D37.1 (K), R24.2
/row2: D3.1 (K), D10.1 (K), D17.1 (K), D24.1 (K), D31.1 (K), D38.1 (K), R25.2
/row3: D4.1 (K), D11.1 (K), D18.1 (K), D25.1 (K), D32.1 (K), R26.2
/row4: D5.1 (K), D12.1 (K), D19.1 (K), D26.1 (K), D33.1 (K), R27.2
/row5: D6.1 (K), D13.1 (K), D20.1 (K), D27.1 (K), D34.1 (K), R28.2
/row6: D7.1 (K), D14.1 (K), D21.1 (K), D28.1 (K), D35.1 (K), R29.2
GND: C1.2, C2.2, C3.2, C4.2, C5.1, C6.2, C7.2, C8.2, C9.2, C10.2, C11.2, C12.2, C13.2, C14.2, C15.2, C16.2, C17.1, C18.1, C19.2, C20.2, C21.2, J1.A1 (GND), J1.A12 (GND), J1.B1 (GND), J1.B12 (GND), J1.S1 (SHIELD), J2.A1 (GND), J2.A12 (GND), J2.B1 (GND), J2.B12 (GND), J2.S1 (SHIELD), J3.3, R1.2, R2.2, SW1.C, SW1.S2, SW2.1, U1.1 (GND), U2.2 (GND), U3.10 (VSS), U3.20 (VSSA), U3.27 (VSS), U3.74 (VSS), U3.94 (BOOT0), U3.99 (VSS), U4.1 (GND), U5.2 (GND)
unnamed: C1.1, U3.49 (VCAP_1)
unnamed: C2.1, U3.73 (VCAP_2)
unnamed: C3.1, FB1.2, U4.3 (VI)
unnamed: C4.1, D40.2 (A), U4.2 (VO)
unnamed: D1.2 (A), K1.2
unnamed: D2.2 (A), K2.2
unnamed: D3.2 (A), K3.2
unnamed: D4.2 (A), K4.2
unnamed: D5.2 (A), K5.2
unnamed: D6.2 (A), K6.2
unnamed: D7.2 (A), K7.2
unnamed: D8.2 (A), K8.2
unnamed: D9.2 (A), K9.2
unnamed: D10.2 (A), K10.2
unnamed: D11.2 (A), K11.2
unnamed: D12.2 (A), K12.2
unnamed: D13.2 (A), K13.2
unnamed: D14.2 (A), K14.2
unnamed: D15.2 (A), K15.2
unnamed: D16.2 (A), K16.2
unnamed: D17.2 (A), K17.2
unnamed: D18.2 (A), K18.2
unnamed: D19.2 (A), K19.2
unnamed: D20.2 (A), K20.2
unnamed: D21.2 (A), K21.2
unnamed: D22.2 (A), K22.2
unnamed: D23.2 (A), K23.2
unnamed: D24.2 (A), K24.2
unnamed: D25.2 (A), K25.2
unnamed: D26.2 (A), K26.2
unnamed: D27.2 (A), K27.2
unnamed: D28.2 (A), K28.2
unnamed: D29.2 (A), K29.2
unnamed: D30.2 (A), K30.2
unnamed: D31.2 (A), K31.2
unnamed: D32.2 (A), K32.2
unnamed: D33.2 (A), K33.2
unnamed: D34.2 (A), K34.2
unnamed: D35.2 (A), K35.2
unnamed: D36.2 (A), K36.2
unnamed: D37.2 (A), K37.2
unnamed: D38.2 (A), K38.2
unnamed: D39.1 (K), FB1.1
unnamed: D41.2 (A), J3.1
unnamed: J1.A5 (CC1), R1.1
unnamed: J1.B5 (CC2), R2.1
unnamed: J2.A2 (TX1+), J2.B2 (TX2+)
unnamed: J2.A3 (TX1-), J2.B3 (TX2-), R20.2
unnamed: J2.A5 (CC1), J2.B5 (CC2), R3.2
unnamed: J2.A6 (D+), J2.B6 (D+), R17.2
unnamed: J2.A7 (D-), J2.B7 (D-), R16.2
unnamed: J2.A8 (SBU1), J2.B8 (SBU2), R21.2
unnamed: J2.A10 (RX2-), J2.B10 (RX1-), R18.2
unnamed: J2.A11 (RX2+), J2.B11 (RX1+), R19.2
unnamed: R11.2, R12.2, SW1.A
unnamed: R13.2, R14.1, SW1.B
unnamed: R22.1, U3.61 (PD14)
unnamed: R23.1, U3.81 (PD0)
unnamed: R24.1, U3.82 (PD1)
unnamed: R25.1, U3.83 (PD2)
unnamed: R26.1, U3.84 (PD3)
unnamed: R27.1, U3.85 (PD4)
unnamed: R28.1, U3.86 (PD5)
unnamed: R29.1, U3.87 (PD6)
unnamed: R30.1, U3.88 (PD7)
unnamed: R31.1, U3.55 (PD8)
unnamed: R32.1, U3.56 (PD9)
unnamed: R33.1, U3.57 (PD10)
unnamed: R34.1, U3.58 (PD11)
unnamed: R35.1, U3.59 (PD12)
unnamed: R36.1, U3.60 (PD13)
unnamed: R37.1, U3.62 (PD15)
unnamed: R40.2, U2.3 (~CS)
unnamed: R43.2, U2.4 (RESET)
unnamed: R44.2, U2.5 (D/~C)
unnamed: R41.2, U2.6 (MOSI)
unnamed: R42.2, U2.7 (SCK)
VBUS: C19.1, C20.1, D39.2 (A), J1.A4 (VBUS), J1.A9 (VBUS), J1.B4 (VBUS), J1.B9 (VBUS), J2.A4 (VBUS), J2.A9 (VBUS), J2.B4 (VBUS), J2.B9 (VBUS), U2.1 (VCC)

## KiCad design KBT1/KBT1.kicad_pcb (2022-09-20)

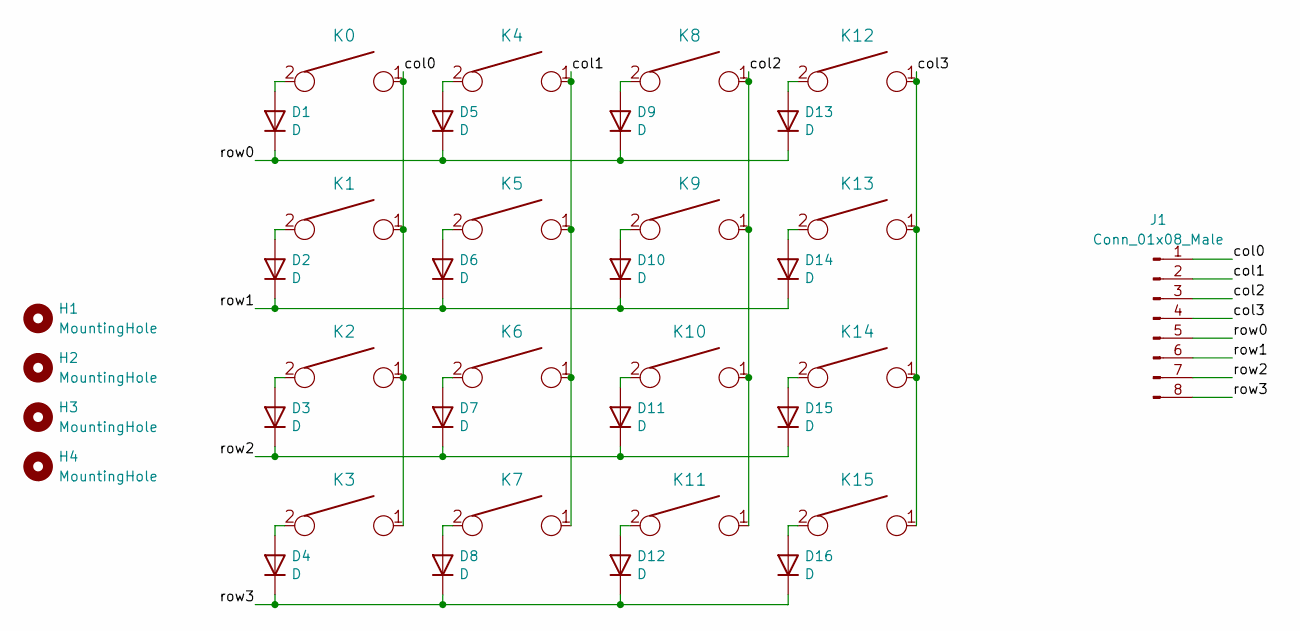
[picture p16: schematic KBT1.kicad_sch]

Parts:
D1, D2, D3, D4, D5, D6, D7, D8, D9, D10, D11, D12, D13, D14, D15, D16: D; D_DO-35_SOD27_P7.62mm_Horizontal
H1, H2, H3, H4: MountingHole; MountingHole_2.7mm
J1: Conn_01x08_Male; PinHeader_1x08_P2.54mm_Vertical
K0, K1, K2, K3, K4, K5, K6, K7, K8, K9, K10, K11, K12, K13, K14, K15: KEYSW; SW_Hotswap_Kailh_MX_plated

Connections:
/col0: J1.1, K0.1, K1.1, K2.1, K3.1
/col1: J1.2, K4.1, K5.1, K6.1, K7.1
/col2: J1.3, K8.1, K9.1, K10.1, K11.1
/col3: J1.4, K12.1, K13.1, K14.1, K15.1
/row0: D1.1 (K), D5.1 (K), D9.1 (K), D13.1 (K), J1.5
/row1: D2.1 (K), D6.1 (K), D10.1 (K), D14.1 (K), J1.6
/row2: D3.1 (K), D7.1 (K), D11.1 (K), D15.1 (K), J1.7
/row3: D4.1 (K), D8.1 (K), D12.1 (K), D16.1 (K), J1.8
unnamed: D1.2 (A), K0.2
unnamed: D2.2 (A), K1.2
unnamed: D3.2 (A), K2.2
unnamed: D4.2 (A), K3.2
unnamed: D5.2 (A), K4.2
unnamed: D6.2 (A), K5.2
unnamed: D7.2 (A), K6.2
unnamed: D8.2 (A), K7.2
unnamed: D9.2 (A), K8.2
unnamed: D10.2 (A), K9.2
unnamed: D11.2 (A), K10.2
unnamed: D12.2 (A), K11.2
unnamed: D13.2 (A), K12.2
unnamed: D14.2 (A), K13.2
unnamed: D15.2 (A), K14.2
unnamed: D16.2 (A), K15.2

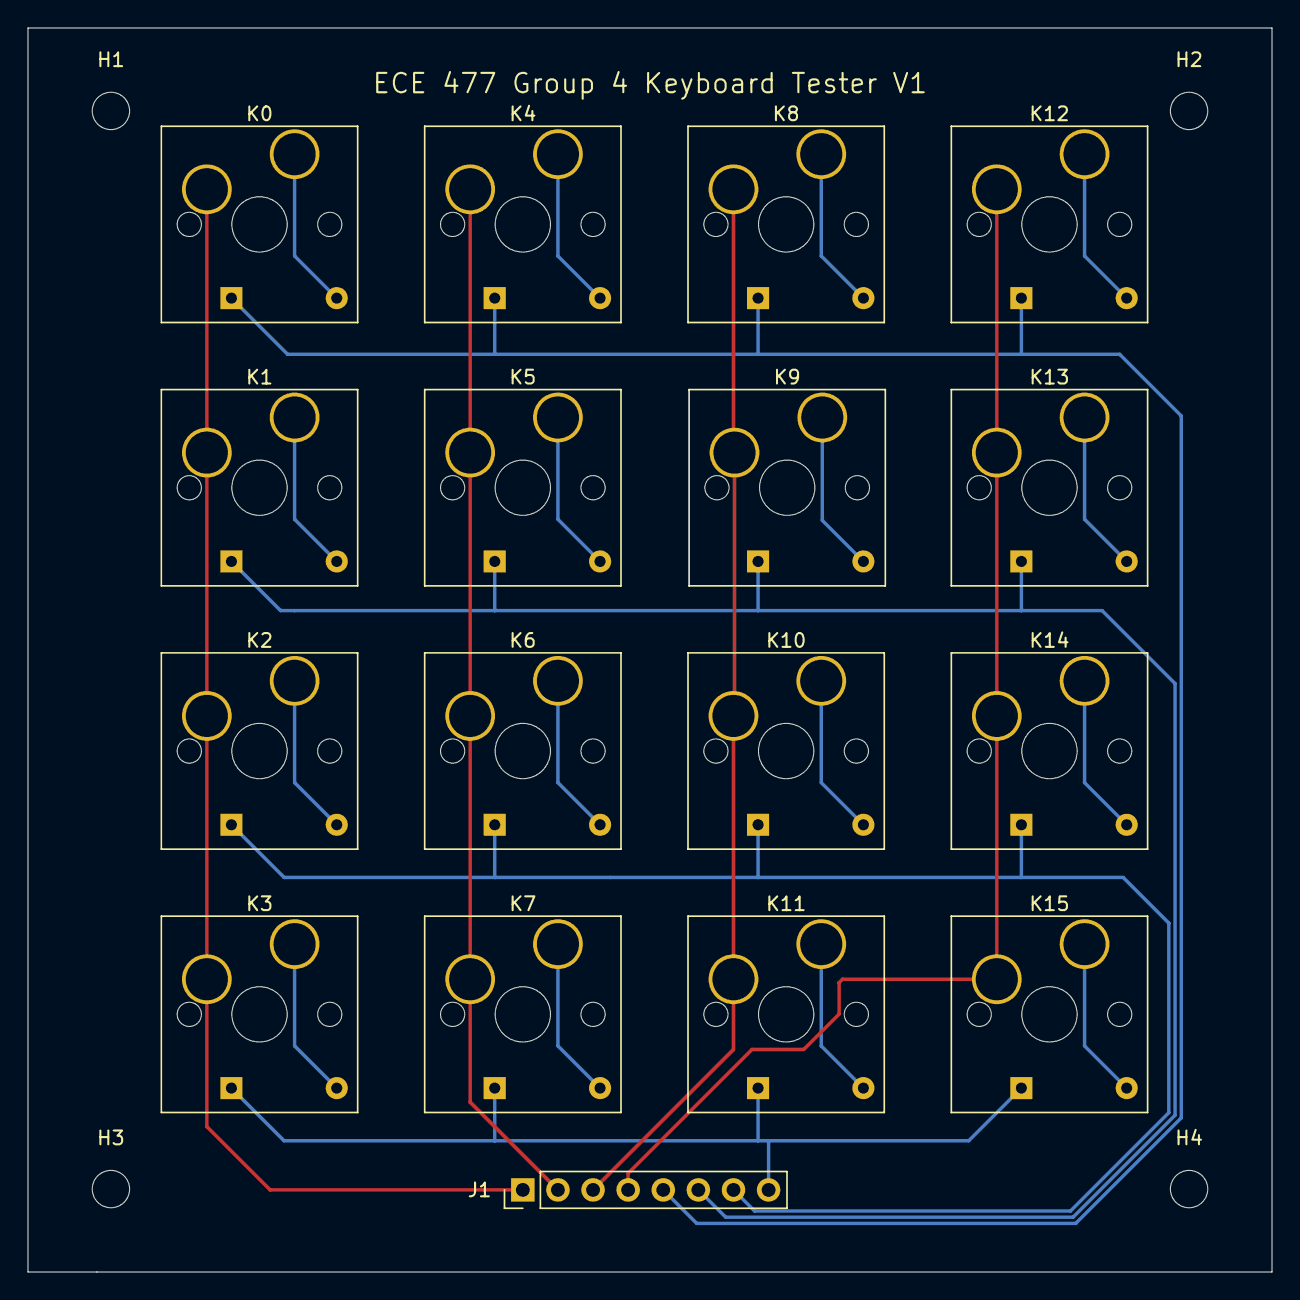
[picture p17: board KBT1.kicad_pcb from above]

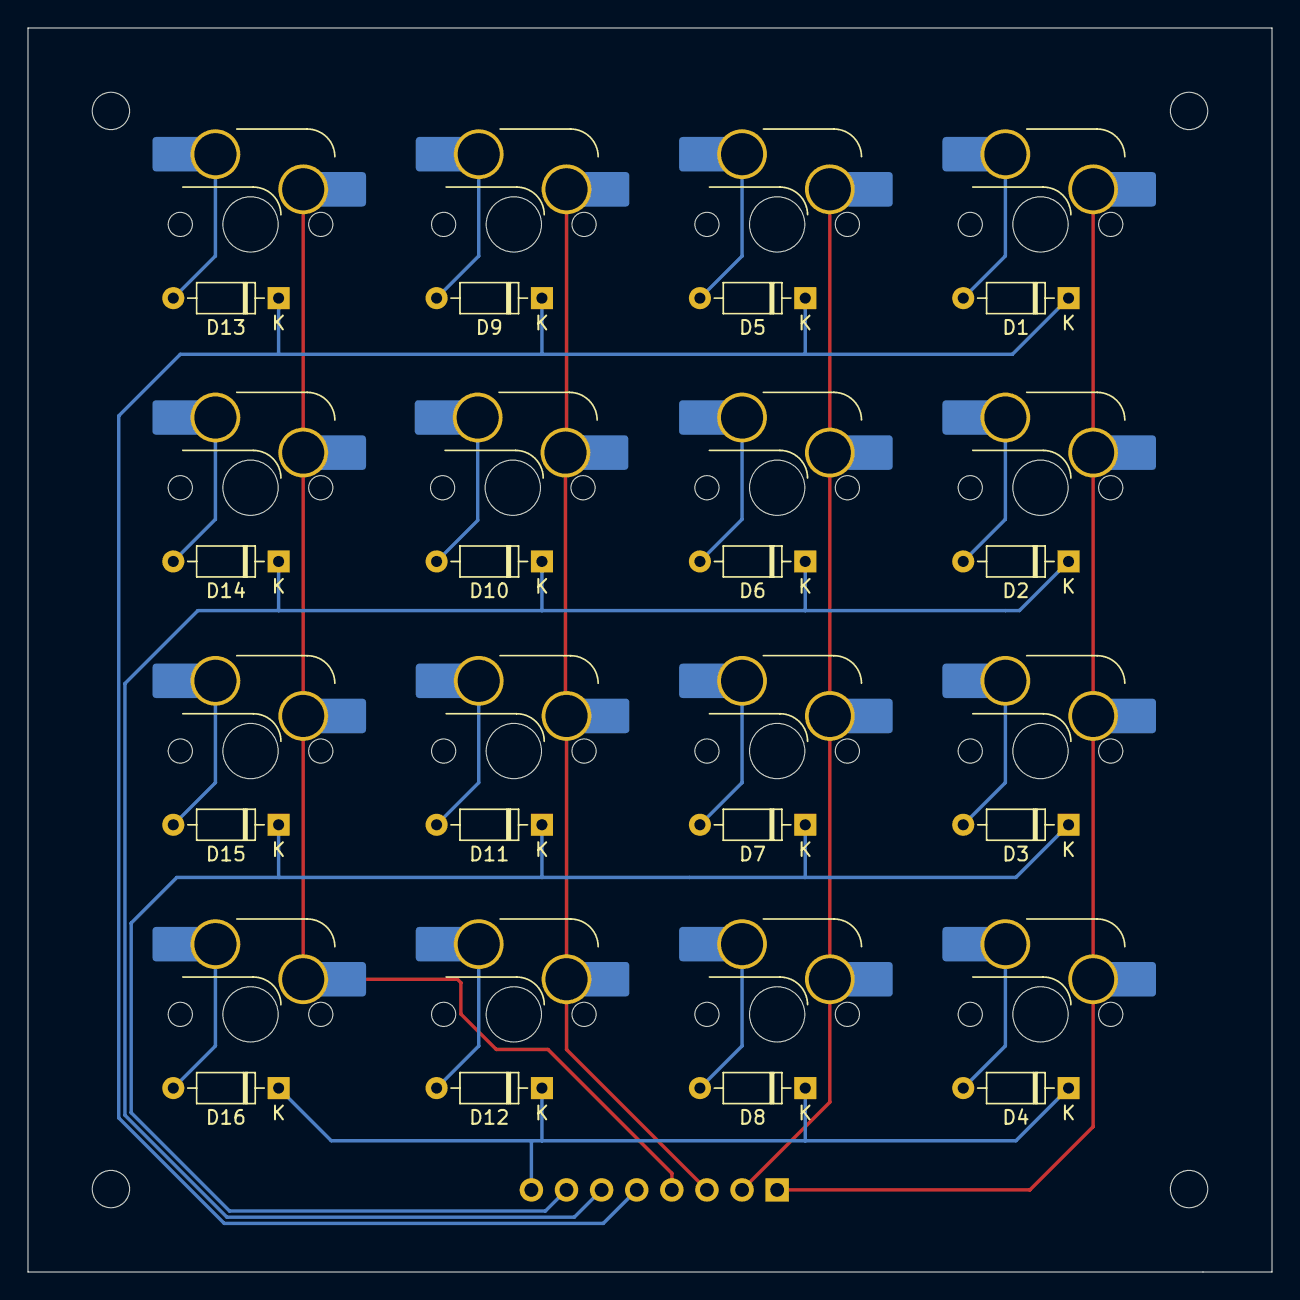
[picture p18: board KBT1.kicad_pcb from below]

Board: 2 copper layers, 90.0 x 90.0 mm, 37 parts (16 on the bottom side), 24 nets.

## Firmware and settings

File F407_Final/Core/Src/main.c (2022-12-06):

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
/* Includes ------------------------------------------------------------------*/
#include "main.h"
#include "usb_device.h"

/* USER CODE BEGIN Includes */
#include "usbd_hid.h"
#include "keycodes.h"
#include "layout.h"
#include "ILI9341_GFX.h"
#include "ILI9341_STM32_Driver.h"

/* USER CODE END Includes */

/* USER CODE BEGIN PD */
#define KEYCODE_LIMIT 6
#define GPIOEX_ADDR (0x20 << 1)

/* USER CODE END PD */

I2C_HandleTypeDef hi2c2;

SPI_HandleTypeDef hspi2;
DMA_HandleTypeDef hdma_spi2_tx;

TIM_HandleTypeDef htim4;
TIM_HandleTypeDef htim6;
TIM_HandleTypeDef htim7;

/* USER CODE BEGIN PV */

// WPM Counters
unsigned int charCount = 0;
unsigned int charsInCycle = 0;
unsigned int numCycles = 0;
unsigned int dryCycles = 0;
float wpm = 0;
float cpm = 0;
int writeScreen = 1;
long totalChars = 0;

// row-column scanning
int keycodeNum = 1;
int row = 0;
int local_cols = 0;
int expander_cols = 0;
int expander_rot = 0; // 3 bits: switch, A, B
int exLastCLK = 0;
int exRotLock = 0;

// rotary direction
int currentStateCLK = 0;
int lastStateCLK = 0;
int currentStateDT = 0;
int rotLock = 0;

// USBD struct
extern USBD_HandleTypeDef hUsbDeviceFS;

typedef struct
{
	uint8_t MODIFIER;
	uint8_t RESERVED;
	uint8_t KEYCODE1;
	uint8_t KEYCODE2;
	uint8_t KEYCODE3;
	uint8_t KEYCODE4;
	uint8_t KEYCODE5;
	uint8_t KEYCODE6;
} keyboardHID;

keyboardHID keyboardhid = {0,0,0,0,0,0,0,0};

/* USER CODE END PV */

void SystemClock_Config(void);
static void MX_GPIO_Init(void);
static void MX_DMA_Init(void);
static void MX_TIM4_Init(void);
static void MX_TIM6_Init(void);
static void MX_TIM7_Init(void);
static void MX_I2C2_Init(void);
static void MX_SPI2_Init(void);
/* USER CODE BEGIN PFP */
// local keypad scanning
void scan_keypad();
void set_rows();
void get_cols();

// rotary encoder scanning
void scan_rotary();

// usb functions
void add_keypress(uint16_t key);
void record_keys();

// LCD functions
void switch_lcd();

/* USER CODE END PFP */

/* USER CODE BEGIN 0 */
/* Local Keypad Scanning */
void scan_keypad() {
  set_rows();

  // update the global variables for col values
  get_cols();

  // scan local cols
  for(int i = 0; i < nCols1; i++) {
    if(local_cols & (1 << i)) {
    	if (keypresses1[row][i] != 1) {
    		keypresses1[row][i] = 1;
    	    // WPM timer not enabled
    	    if (!(TIM1->CR1 && TIM_CR1_CEN)) {
    	    	HAL_TIM_Base_Start_IT(&htim7);
    	    }
    	    charCount++;
    	    totalChars++;
    	    charsInCycle++;
    	}
    }
    else {
      keypresses1[row][i] = 0;
    }
  }

  // scan expander cols
  for(int i = 0; i < nCols2; i++) {
    if(expander_cols & (1 << i)) {
      if (keypresses2[row][i] != 1) {
    	  keypresses2[row][i] = 1;
    	  // WPM timer not enabled
    	  if (!(TIM1->CR1 && TIM_CR1_CEN)) {
    		  HAL_TIM_Base_Start_IT(&htim7);
    	  }
    	  charCount++;
    	  totalChars++;
    	  charsInCycle++;
      }
    }
    else {
      keypresses2[row][i] = 0;
    }

  }

}

void set_rows() {
  // update row value
  row = (row + 1) % nRows1;
  HAL_GPIO_WritePin(GPIOD, ROW0_Pin, GPIO_PIN_SET);
  HAL_GPIO_WritePin(GPIOD, ROW1_Pin, GPIO_PIN_SET);
  HAL_GPIO_WritePin(GPIOD, ROW2_Pin, GPIO_PIN_SET);
  HAL_GPIO_WritePin(GPIOD, ROW3_Pin, GPIO_PIN_SET);
  HAL_GPIO_WritePin(GPIOD, ROW4_Pin, GPIO_PIN_SET);
  HAL_GPIO_WritePin(GPIOD, ROW5_Pin, GPIO_PIN_SET);
  HAL_GPIO_WritePin(GPIOD, ROW6_Pin, GPIO_PIN_SET);

  // use global variable row to set the correct row to low and last row back to high
  switch(row) {
    case 0:
      HAL_GPIO_WritePin(GPIOD, ROW0_Pin, GPIO_PIN_RESET);
      break;
    case 1:
      HAL_GPIO_WritePin(GPIOD, ROW1_Pin, GPIO_PIN_RESET);
      break;
    case 2:
      HAL_GPIO_WritePin(GPIOD, ROW2_Pin, GPIO_PIN_RESET);
      break;
    case 3:
      HAL_GPIO_WritePin(GPIOD, ROW3_Pin, GPIO_PIN_RESET);
      break;
    case 4:
      HAL_GPIO_WritePin(GPIOD, ROW4_Pin, GPIO_PIN_RESET);
      break;
    case 5:
	  HAL_GPIO_WritePin(GPIOD, ROW5_Pin, GPIO_PIN_RESET);
	  break;
    case 6:
	  HAL_GPIO_WritePin(GPIOD, ROW6_Pin, GPIO_PIN_RESET);
	  break;
  }

  // ! GPIOB2 - GPIOB7 maps to row0 - row5, GPIOA7 maps to row6
  if (row != 6){
	  uint8_t data[3] = {0x14, ~0, ~( 0x04 << row )}; // addr 0x14 for IOCON.BANK = 0, 0x0A for IOCON.BANK = 1
	  HAL_I2C_Master_Transmit(&hi2c2, GPIOEX_ADDR, data, 3, 1000);
  } else {
	  uint8_t data[3] = {0x14, ~0x80, ~0}; // addr 0x14 for IOCON.BANK = 0, 0x0A for IOCON.BANK = 1
	  HAL_I2C_Master_Transmit(&hi2c2, GPIOEX_ADDR, data, 3, 1000);
  }
}

void get_cols() {
  // get the value of all columns as one int from the GPIO register
  // PD7-4
  local_cols = ~(GPIOD->IDR >> 7) & 0x3F;

  // read the GPIO expander columns
  // ! GPIOA0 - GPIOA5 maps to col0 - col5
  uint8_t data[2] = {0x12, 0x00}; // addr 0x12 for IOCON.BANK = 0, 0x09 for IOCON.BANK = 1
  HAL_I2C_Master_Transmit(&hi2c2, GPIOEX_ADDR, data, 1, 1000);
  HAL_I2C_Master_Receive(&hi2c2, GPIOEX_ADDR, data, 2, 1000);

  expander_cols = data[0] & 0x3F;

  expander_rot = (data[1] & 0x03) | ((data[0] & 0x40) >> 4); // switch, A, B
}

/* Rotary Encoder Scanning */
void scan_rotary() {
  currentStateCLK = HAL_GPIO_ReadPin(GPIOD, ENC_A_Pin);

  // if CLK pin has changed, then the rotary encoder has turned
  if (currentStateCLK != lastStateCLK && rotLock == 0 ) {// && rotLock == 0) {
    // if the DT state is different, then the encoder is rotating counter-clockwise
    currentStateDT = HAL_GPIO_ReadPin(GPIOD, ENC_B_Pin);

    if (currentStateDT != currentStateCLK) {
      // Volume Down
      rotary_keypresses1[1] = 1;
    }

    // otherwise, it is turning clockwise
    else if (currentStateDT == currentStateCLK) {
      // Volume Up
      rotary_keypresses1[2] = 1;
    }
    rotLock++;

  }
  else if (rotLock == 0) {
	  rotary_keypresses1[1] = 0;
	  rotary_keypresses1[2] = 0;
  }

  lastStateCLK = currentStateCLK;

  // rotLock allows the rotary encoder's inputs to settle over a few extra clock cycles
  if(rotLock != 0) {
    rotLock = (rotLock + 1) % 150;
  }

  // if the state is low (default is high), turn toggle the LED
  if (HAL_GPIO_ReadPin(GPIOD, ENC_SW_Pin) == 0) {
    // Volume Mute Toggle
	  rotary_keypresses1[0] = 1;
  }
  else {
	  rotary_keypresses1[0] = 0;
  }

  // Expander rotary encoder
  int exCLK  = (expander_rot & 0x01);
  int exDT = (expander_rot & 0x02) >> 1;
  int exSW  = (expander_rot & 0x04) >> 2;

  // if CLK pin has changed, then the rotary encoder has turned
  if (exCLK != exLastCLK && exRotLock == 0 ) {// && rotLock == 0) {
	  // if the DT state is different, then the encoder is rotating counter-clockwise

	  if (exDT != exCLK) {
		// Volume Down
		rotary_keypresses2[1] = 1;
	  }

	  // otherwise, it is turning clockwise
	  else if (exDT == exCLK) {
		// Volume Up
		rotary_keypresses2[2] = 1;
	  }
	  exRotLock++;

  }
  else if (exRotLock == 0) {
	  rotary_keypresses2[1] = 0;
	  rotary_keypresses2[2] = 0;
  }

  exLastCLK = exCLK;

  if(exRotLock != 0) {
      exRotLock = (exRotLock + 1) % 150;
  }

  if(exSW)
	  rotary_keypresses2[0] = 1;
  else
	  rotary_keypresses2[0] = 0;


}
/* END Rotary Encoder Scanning */

/* USB Functions */
void record_keys() {
  // reset keyboardhid to 0
  memset(&keyboardhid, 0, sizeof(keyboardHID));
  keycodeNum = 1;

  // Add local keypresses
  for(int i = 0; i < nRows1; i++) {
	  for(int j = 0; j < nCols1; j++) {
		  if(keypresses1[i][j] == 1) {
			  add_keypress(layout1[i][j]);
	    }
	  }
  }

  // Add GPIO Expander keypresses
  for(int i = 0; i < nRows2; i++) {
	  for(int j = 0; j < nCols2; j++) {
		  if(keypresses2[i][j] == 1) {
			  add_keypress(layout2[i][j]);
		  }
	  }
  }

  // Add Rotary Encoder keypresses
  for(int i = 0; i < 4; i++) {
	  if(rotary_keypresses1[i] == 1)
		  add_keypress(rotary_keys1[i]);
  }

  // Add Expander Rotary Encoder
  for(int i = 0; i < 4; i++) {
	  if(rotary_keypresses2[i] == 1)
		  add_keypress(rotary_keys2[i]);
   }

}

void add_keypress(uint16_t key) {

	if( (key & 0xFF00) == 0xFF00) {
		int shift = key & 0xFF;
		keyboardhid.MODIFIER |= (1<<shift);

		return;
	}

	switch(keycodeNum) {
		case 1:
		  keyboardhid.KEYCODE1 = key;
		  break;
		case 2:
		  keyboardhid.KEYCODE2 = key;
		  break;
		case 3:
		  keyboardhid.KEYCODE3 = key;
		  break;
		case 4:
		  keyboardhid.KEYCODE4 = key;
		  break;
		case 5:
		  keyboardhid.KEYCODE5 = key;
		  break;
		case 6:
		  keyboardhid.KEYCODE6 = key;
		  break;
		default:
			break;
	}
	keycodeNum++;

}
/* END USB Functions */

/* LCD Functions */
void switch_lcd() {
  // switch LCD_*_PIN and LCD_*_PORT between LCD1_* and LCD2_*
  if(LCD_DC_PIN == LCD2_DC_PIN) {
	LCD_CS_PORT = LCD1_CS_PORT;
	LCD_CS_PIN = LCD1_CS_PIN;
	LCD_DC_PORT = LCD1_DC_PORT;
	LCD_DC_PIN = LCD1_DC_PIN;
	LCD_RST_PORT = LCD1_RST_PORT;
	LCD_RST_PIN = LCD1_RST_PIN;
  }
  else {
	LCD_CS_PORT = LCD2_CS_PORT;
	LCD_CS_PIN = LCD2_CS_PIN;
	LCD_DC_PORT = LCD2_DC_PORT;
	LCD_DC_PIN = LCD2_DC_PIN;
	LCD_RST_PORT = LCD2_RST_PORT;
	LCD_RST_PIN = LCD2_RST_PIN;
  }
}
/* END LCD Functions */


/* USER CODE END 0 */

/**
  * @brief  The application entry point.
  * @retval int
  */
int main(void)
{
  /* MCU Configuration--------------------------------------------------------*/

  /* Reset of all peripherals, Initializes the Flash interface and the Systick. */
  HAL_Init();

  /* USER CODE BEGIN Init */
  //HAL_Delay(2000);
  /* USER CODE END Init */

  /* Configure the system clock */
  SystemClock_Config();

  /* Initialize all configured peripherals */
  MX_GPIO_Init();
  MX_DMA_Init();
  MX_USB_DEVICE_Init();
  MX_TIM4_Init();
  MX_TIM6_Init();
  MX_TIM7_Init();
  MX_I2C2_Init();
  MX_SPI2_Init();
  /* USER CODE BEGIN 2 */

  // Initialize the LCDs
  // Left Screen
  char writeBuff[20];
  ILI9341_Init();
  ILI9341_SetRotation(SCREEN_VERTICAL_1);
  ILI9341_FillScreen(BLACK);
//  sprintf(writeBuff, "Characters");
//  ILI9341_DrawText(writeBuff, FONT5, 25, 85, WHITE, BLACK);
//  sprintf(writeBuff, "Pressed ");
//  ILI9341_DrawText(writeBuff, FONT5, 25, 135, WHITE, BLACK);
  sprintf(writeBuff, "Characters");
  ILI9341_DrawText(writeBuff, FONT5, 10, 85, WHITE, BLACK);
  sprintf(writeBuff, "Per");
  ILI9341_DrawText(writeBuff, FONT5, 10, 135, WHITE, BLACK);
  sprintf(writeBuff, "Minute:");
  ILI9341_DrawText(writeBuff, FONT5, 10, 185, WHITE, BLACK);
  sprintf(writeBuff, "Total Pressed:");
  ILI9341_DrawText(writeBuff, FONT4, 10, 290, WHITE, BLACK);

  // Right Screen
  switch_lcd();
  ILI9341_Init();
  ILI9341_SetRotation(SCREEN_VERTICAL_1);
  ILI9341_FillScreen(BLACK);
  sprintf(writeBuff, "Words");
  ILI9341_DrawText(writeBuff, FONT5, 25, 85, WHITE, BLACK);
  sprintf(writeBuff, "Per");
  ILI9341_DrawText(writeBuff, FONT5, 25, 135, WHITE, BLACK);
  sprintf(writeBuff, "Minute:");
  ILI9341_DrawText(writeBuff, FONT5, 25, 185, WHITE, BLACK);

  // start the timer interrupt
  HAL_TIM_Base_Start_IT(&htim4);
  HAL_TIM_Base_Start_IT(&htim6);

  /* USER CODE END 2 */

  /* Infinite loop */
  /* USER CODE BEGIN WHILE */

  char buffer1[10];
  char buffer2[10];

  while (1)
  {
//	  //draw the counter to the lcd
	  if (writeScreen) {
		  sprintf(buffer1, "%-3d", (int)wpm);
	  	  ILI9341_DrawText(buffer1, FONT5, 	165, 185, WHITE, BLACK);

	  	  switch_lcd();

	  	  sprintf(buffer2, "%-4d", (int)cpm);
	  	  ILI9341_DrawText(buffer2, FONT5, 150, 185, WHITE, BLACK);


	  	  sprintf(buffer2, "%9ld", totalChars);
	  	  ILI9341_DrawText(buffer2, FONT4, 140, 290, WHITE, BLACK);
	  	  writeScreen = 0;

	  	  switch_lcd();
	  }

    /* USER CODE END WHILE */

    /* USER CODE BEGIN 3 */
  }
  /* USER CODE END 3 */
}

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
/* USER CODE BEGIN 4 */

// Callback: timer has reset
void HAL_TIM_PeriodElapsedCallback(TIM_HandleTypeDef *htim) {

	// Send USB data
	if (htim == &htim4) {
	    // send HID report
		record_keys();
		USBD_HID_SendReport(&hUsbDeviceFS, (uint8_t*) &keyboardhid, sizeof(keyboardhid));
	}

	// Keypad scanning
	else if (htim == &htim6) {

		/* Row-Col Scanning */
		scan_keypad();

		/* Rotary Encoder */
		scan_rotary();
	}

	else if (htim == &htim7) {
//		// words per minute
//		// check to see if any keys pressed
		if (charsInCycle == 0) {
			dryCycles++;
			// shut down if 5 cycles with no presses
			if (dryCycles == 5) {
				charCount = 0;
				charsInCycle = 0;
				dryCycles = 0;
				numCycles = 0;
				HAL_TIM_Base_Stop_IT(&htim7);
			}
		}
		// calculate wpm
		numCycles++;
		wpm = (charCount / 5.0f) / ((2.0f * numCycles) / 60.0f);
		cpm = (charCount) / ((2.0f * numCycles) / 60.0f);
		charsInCycle = 0;
		writeScreen = 1;

	}
}

/* USER CODE END 4 */
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


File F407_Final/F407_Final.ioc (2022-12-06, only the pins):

Mcu.UserName=STM32F407VGTx
PA10.GPIO_Label=LCD1_RST
PA10.Signal=GPIO_Output
PA11.Signal=USB_OTG_FS_DM
PA12.Signal=USB_OTG_FS_DP
PA13.Signal=SYS_JTMS-SWDIO
PA14.Signal=SYS_JTCK-SWCLK
PA8.GPIO_Label=LCD2_CS
PA8.Signal=GPIO_Output
PA9.GPIO_Label=LCD2_RST
PA9.Signal=GPIO_Output
PB10.Signal=I2C2_SCL
PB11.Signal=I2C2_SDA
PB13.Signal=SPI2_SCK
PC3.Signal=SPI2_MOSI
PC7.GPIO_Label=LCD1_DC
PC7.Signal=GPIO_Output
PC8.GPIO_Label=LCD1_CS
PC8.Signal=GPIO_Output
PC9.GPIO_Label=LCD2_DC
PC9.Signal=GPIO_Output
PD0.GPIO_Label=ROW0
PD0.Signal=GPIO_Output
PD1.GPIO_Label=ROW1
PD1.Signal=GPIO_Output
PD10.GPIO_Label=COL3
PD10.Signal=GPIO_Input
PD11.GPIO_Label=COL4
PD11.Signal=GPIO_Input
PD12.GPIO_Label=COL5
PD12.Signal=GPIO_Input
PD13.GPIO_Label=ENC_A
PD13.Signal=GPIO_Input
PD14.GPIO_Label=ENC_B
PD14.Signal=GPIO_Input
PD15.GPIO_Label=ENC_SW
PD15.Signal=GPIO_Input
PD2.GPIO_Label=ROW2
PD2.Signal=GPIO_Output
PD3.GPIO_Label=ROW3
PD3.Signal=GPIO_Output
PD4.GPIO_Label=ROW4
PD4.Signal=GPIO_Output
PD5.GPIO_Label=ROW5
PD5.Signal=GPIO_Output
PD6.GPIO_Label=ROW6
PD6.Signal=GPIO_Output
PD7.GPIO_Label=COL0
PD7.Signal=GPIO_Input
PD8.GPIO_Label=COL1
PD8.Signal=GPIO_Input
PD9.GPIO_Label=COL2
PD9.Signal=GPIO_Input
PH0-OSC_IN.Signal=RCC_OSC_IN
PH1-OSC_OUT.Signal=RCC_OSC_OUT

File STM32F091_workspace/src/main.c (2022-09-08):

/**
  ******************************************************************************
  * @file    main.c
  * @author  Ac6
  * @version V1.0
  * @date    01-December-2013
  * @brief   Default main function.
  ******************************************************************************
*/


#include "stm32f0xx.h"

char offset;
char history[16];
char queue[2];
int  qin;
int  qout;			

void enable_ports(void) {
	// Turn on GPIOA and GPIOB clocks
	RCC->AHBENR |= RCC_AHBENR_GPIOAEN | RCC_AHBENR_GPIOBEN;

  // Configure PB0-PB3 to be outputs
  GPIOB->MODER &= ~0xff;
  GPIOB->MODER |= 0x55;

  // configure PA0-PA3 to be outputs
  GPIOA->MODER &= ~0xff;
  GPIOA->MODER |= 0x55;

  // configure PA4-PA7 to be inputs
  GPIOA->MODER &= ~0xff00;

  // configure internal pull down resistors for PA4-PA7
  GPIOA->PUPDR &= ~0xff00;
  GPIOA->PUPDR |= 0xaa00;

}

//===========================================================================
// insert_queue()    (Autotest #7)
// Insert the key index number into the two-entry queue.
// Parameters: n: the key index number
//===========================================================================
void insert_queue(int n)
{
    n |= 0x80;
    queue[qin] = n;
    qin ^= 1;
}

//===========================================================================
// update_hist()    (Autotest #8)
// Check the columns for a row of the keypad and update history values.
// If a history entry is updated to 0x01, insert it into the queue.
// Parameters: none
//===========================================================================
void update_hist(int cols)
{
    int row = offset & 3;
    for(int i=0; i < 4; i++) {
        history[4*row+i] = (history[4*row+i]<<1) + ((cols>>i)&1);
        if(history[4*row+i] == 0x1)
            insert_queue(4*row+i);
    }
}

//===========================================================================
// set_row()    ( #5)
// Set the row active on the keypad matrix.
// Parameters: none
//===========================================================================
void set_row()
{
    char lower2_offset = offset & 3;
    GPIOA->ODR |= 1<<lower2_offset;
    GPIOA->ODR &= 0xfff0 + (1<<lower2_offset);
}

//===========================================================================
// get_cols()    ( #6)
// Read the column pins of the keypad matrix.
// Parameters: none
// Return value: The 4-bit value read from PC[7:4].
//===========================================================================
int get_cols()
{
    int cols = GPIOA->IDR;
    cols = cols>>4;
    cols &= 15;
    return cols;
}

//===========================================================================
// Timer 7 ISR()    ( #9)
// This is the Timer 7 ISR
// Parameters: none
// (Write the entire subroutine below.)
//===========================================================================
void TIM7_IRQHandler()
{
    // acknowledge interrupt
    TIM7->SR &= ~1;

    // call functions
    update_hist(get_cols());

    // update offset
    offset = (offset + 1) & 0x7;
    set_row();
}

//===========================================================================
// setup_tim7()    ( #10)
// Configure timer 7
// Parameters: none
//===========================================================================
void setup_tim7()
{
    // enable RCC clock for TIM7
    RCC->APB1ENR |= 1<<5;

    // set PSC and ARR to interrupt once per millisecond
    TIM7->PSC = 120-1;
    TIM7->ARR = 400-1;

    // enable UIE bit in the DIER
    TIM7->DIER |= TIM_DIER_UIE;

    // enable tim7 in NVIC ISER
    NVIC->ISER[0] = 1<<TIM7_IRQn;

    // set the CEN bit in TIM7_CR1
    TIM7->CR1 |= TIM_CR1_CEN;
}

// function to scan the keypad
// char scanKeypad(void) {
//   int row, col;

//   // Change the state of one row at a time
//   for (row = 0; row < 4; row++) {
//     // Set all rows to 0
//     GPIOA->ODR &= ~(0xF << 4);

//     // Set the current row to 1
//     GPIOA->ODR |= (1 << (row + 4));

//     // Check if any column is 1
//     if ((GPIOA->IDR & 0xF) != 0xF) {
//       // Check which column is 1
//       for (col = 0; col < 4; col++) {
//         if ((GPIOA->IDR & (1 << col)) == 0) {
//           return key_array[row][col];
//         }
//       }
//     }
//   }

//   return '0';
// }

//===========================================================================
// show_digit()    ( #4)
// Output a single digit on the seven-segmnt LED array.
// Parameters: none
//===========================================================================
void show_digit(char key)
{
  // set PB0-3 to low
  GPIOB->ODR &= ~(0xF);

  // Light up PB0 if key is 1, 3, 5, 7, 9, B, D, or #
  if (key == '1' || key == '3' || key == '5' || key == '7' || key == '9' || key == 'B' || key == 'D' || key == '#') {
    GPIOB->ODR |= (1 << 0);
  } else {
    GPIOB->ODR &= ~(1 << 0);
  }

  // Light up PB1 if key is 2, 3, 6, 7, A, B, *, or #
  if (key == '2' || key == '3' || key == '6' || key == '7' || key == 'A' || key == 'B' || key == '*' || key == '#') {
    GPIOB->ODR |= (1 << 1);
  } else {
    GPIOB->ODR &= ~(1 << 1);
  }

  // Light up PB2 if key is 4, 5, 6, 7, C, D, *, or #
  if (key == '4' || key == '5' || key == '6' || key == '7' || key == 'C' || key == 'D' || key == '*' || key == '#') {
    GPIOB->ODR |= (1 << 2);
  } else {
    GPIOB->ODR &= ~(1 << 2);
  }
  
  //Light up PB3 if key is 8, 9, A, B, C, D, *, or #
  if (key == '8' || key == '9' || key == 'A' || key == 'B' || key == 'C' || key == 'D' || key == '*' || key == '#') {
    GPIOB->ODR |= (1 << 3);
  } else {
    GPIOB->ODR &= ~(1 << 3);
  }
}

//===========================================================================
// getkey()    (Autotest #11)
// Wait for an entry in the queue.  Translate it to ASCII.  Return it.
// Parameters: none
// Return value: The ASCII value of the button pressed.
//===========================================================================
int getkey()
{
    // wait for initial interrupt
    asm volatile("wfi");
    // keep waiting while queue[qout] is 0
    while(queue[qout] == 0)
        asm volatile("wfi");

    // save copy, set to 0, toggle qout
    char queue_copy = queue[qout];
    queue[qout] = 0;
    qout ^= 1;

    // AND copy with 0x7f
    queue_copy &= 0x7f;

    if(queue_copy == 0)
        return '1';
    if(queue_copy == 1)
        return '4';
    if(queue_copy == 2)
        return '7';
    if(queue_copy == 3)
        return '*';
    if(queue_copy == 4)
        return '2';
    if(queue_copy == 5)
        return '5';
    if(queue_copy == 6)
        return '8';
    if(queue_copy == 7)
        return '0';
    if(queue_copy == 8)
        return '3';
    if(queue_copy == 9)
        return '6';
    if(queue_copy == 10)
        return '9';
    if(queue_copy == 11)
        return '#';
    if(queue_copy == 12)
        return 'A';
    if(queue_copy == 13)
        return 'B';
    if(queue_copy == 14)
        return 'C';
    if(queue_copy == 15)
        return 'D';
}
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

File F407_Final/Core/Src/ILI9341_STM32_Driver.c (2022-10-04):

#include "ILI9341_STM32_Driver.h"

volatile uint16_t LCD_HEIGHT = ILI9341_SCREEN_HEIGHT;
volatile uint16_t LCD_WIDTH	 = ILI9341_SCREEN_WIDTH;
GPIO_TypeDef* LCD_CS_PORT = LCD1_CS_PORT;
uint16_t LCD_CS_PIN = LCD1_CS_PIN;
GPIO_TypeDef* LCD_DC_PORT = LCD1_DC_PORT;
uint16_t LCD_DC_PIN = LCD1_DC_PIN;
GPIO_TypeDef* LCD_RST_PORT = LCD1_RST_PORT;
uint16_t LCD_RST_PIN = LCD1_RST_PIN;

void HAL_SPI_TxCpltCallback(SPI_HandleTypeDef *hspi)
{
  /* Deselect when Tx Complete */
  if(hspi == HSPI_INSTANCE)
  {
	  HAL_GPIO_WritePin(LCD_CS_PORT, LCD_CS_PIN, GPIO_PIN_SET);
  }
}

static void ILI9341_SPI_Tx(uint8_t data)
{
	while(!__HAL_SPI_GET_FLAG(HSPI_INSTANCE, SPI_FLAG_TXE));
	HAL_SPI_Transmit_DMA(HSPI_INSTANCE, &data, 1);
	//HAL_SPI_Transmit(HSPI_INSTANCE, &data, 1, 10);
}

static void ILI9341_SPI_TxBuffer(uint8_t *buffer, uint16_t len)
{
	while(!__HAL_SPI_GET_FLAG(HSPI_INSTANCE, SPI_FLAG_TXE));
	HAL_SPI_Transmit_DMA(HSPI_INSTANCE, buffer, len);
	//HAL_SPI_Transmit(HSPI_INSTANCE, buffer, len, 10);
}

void ILI9341_WriteCommand(uint8_t cmd)
{
	HAL_GPIO_WritePin(LCD_DC_PORT, LCD_DC_PIN, GPIO_PIN_RESET);	//command
	HAL_GPIO_WritePin(LCD_CS_PORT, LCD_CS_PIN, GPIO_PIN_RESET);	//select
	ILI9341_SPI_Tx(cmd);
	//HAL_GPIO_WritePin(LCD_CS_PORT, LCD_CS_PIN, GPIO_PIN_SET);	//deselect
}

void ILI9341_WriteData(uint8_t data)
{
	HAL_GPIO_WritePin(LCD_DC_PORT, LCD_DC_PIN, GPIO_PIN_SET);	//data
	HAL_GPIO_WritePin(LCD_CS_PORT, LCD_CS_PIN, GPIO_PIN_RESET);	//select
	ILI9341_SPI_Tx(data);
	//HAL_GPIO_WritePin(LCD_CS_PORT, LCD_CS_PIN, GPIO_PIN_SET);	//deselect
}

void ILI9341_WriteBuffer(uint8_t *buffer, uint16_t len)
{
	HAL_GPIO_WritePin(LCD_DC_PORT, LCD_DC_PIN, GPIO_PIN_SET);	//data
	HAL_GPIO_WritePin(LCD_CS_PORT, LCD_CS_PIN, GPIO_PIN_RESET);	//select
	ILI9341_SPI_TxBuffer(buffer, len);
	//HAL_GPIO_WritePin(LCD_CS_PORT, LCD_CS_PIN, GPIO_PIN_SET);	//deselect
}

void ILI9341_SetAddress(uint16_t x1, uint16_t y1, uint16_t x2, uint16_t y2)
{
	uint8_t buffer[4];
	buffer[0] = x1 >> 8;
	buffer[1] = x1;
	buffer[2] = x2 >> 8;
	buffer[3] = x2;

	ILI9341_WriteCommand(0x2A);
	ILI9341_WriteBuffer(buffer, sizeof(buffer));

	buffer[0] = y1 >> 8;
	buffer[1] = y1;
	buffer[2] = y2 >> 8;
	buffer[3] = y2;

	ILI9341_WriteCommand(0x2B);
	ILI9341_WriteBuffer(buffer, sizeof(buffer));

	ILI9341_WriteCommand(0x2C);
}

void ILI9341_Reset(void)
{
	HAL_GPIO_WritePin(LCD_RST_PORT, LCD_RST_PIN, GPIO_PIN_RESET);	//Disable
	HAL_Delay(10);
	HAL_GPIO_WritePin(LCD_CS_PORT, LCD_CS_PIN, GPIO_PIN_RESET);		//Select
	HAL_Delay(10);
	HAL_GPIO_WritePin(LCD_RST_PORT, LCD_RST_PIN, GPIO_PIN_SET);		//Enable
	HAL_GPIO_WritePin(LCD_CS_PORT, LCD_CS_PIN, GPIO_PIN_SET); 		//Deselect
}

void ILI9341_Enable(void)
{
	HAL_GPIO_WritePin(LCD_RST_PORT, LCD_RST_PIN, GPIO_PIN_SET);		//Enable
}

void ILI9341_Init(void)
{
	ILI9341_Enable();
	ILI9341_Reset();

	//SOFTWARE RESET
	ILI9341_WriteCommand(0x01);
	HAL_Delay(10);

	//POWER CONTROL A
	ILI9341_WriteCommand(0xCB);
	ILI9341_WriteData(0x39);
	ILI9341_WriteData(0x2C);
	ILI9341_WriteData(0x00);
	ILI9341_WriteData(0x34);
	ILI9341_WriteData(0x02);

	//POWER CONTROL B
	ILI9341_WriteCommand(0xCF);
	ILI9341_WriteData(0x00);
	ILI9341_WriteData(0xC1);
	ILI9341_WriteData(0x30);

	//DRIVER TIMING CONTROL A
	ILI9341_WriteCommand(0xE8);
	ILI9341_WriteData(0x85);
	ILI9341_WriteData(0x00);
	ILI9341_WriteData(0x78);

	//DRIVER TIMING CONTROL B
	ILI9341_WriteCommand(0xEA);
	ILI9341_WriteData(0x00);
	ILI9341_WriteData(0x00);

	//POWER ON SEQUENCE CONTROL
	ILI9341_WriteCommand(0xED);
	ILI9341_WriteData(0x64);
	ILI9341_WriteData(0x03);
	ILI9341_WriteData(0x12);
	ILI9341_WriteData(0x81);

	//PUMP RATIO CONTROL
	ILI9341_WriteCommand(0xF7);
	ILI9341_WriteData(0x20);

	//POWER CONTROL,VRH[5:0]
	ILI9341_WriteCommand(0xC0);
	ILI9341_WriteData(0x23);

	//POWER CONTROL,SAP[2:0];BT[3:0]
	ILI9341_WriteCommand(0xC1);
	ILI9341_WriteData(0x10);

	//VCM CONTROL
	ILI9341_WriteCommand(0xC5);
	ILI9341_WriteData(0x3E);
	ILI9341_WriteData(0x28);

	//VCM CONTROL 2
	ILI9341_WriteCommand(0xC7);
	ILI9341_WriteData(0x86);

	//MEMORY ACCESS CONTROL
	ILI9341_WriteCommand(0x36);
	ILI9341_WriteData(0x48);

	//PIXEL FORMAT
	ILI9341_WriteCommand(0x3A);
	ILI9341_WriteData(0x55);

	//FRAME RATIO CONTROL, STANDARD RGB COLOR
	ILI9341_WriteCommand(0xB1);
	ILI9341_WriteData(0x00);
	ILI9341_WriteData(0x18);

	//DISPLAY FUNCTION CONTROL
	ILI9341_WriteCommand(0xB6);
	ILI9341_WriteData(0x08);
	ILI9341_WriteData(0x82);
	ILI9341_WriteData(0x27);

	//3GAMMA FUNCTION DISABLE
	ILI9341_WriteCommand(0xF2);
	ILI9341_WriteData(0x00);

	//GAMMA CURVE SELECTED
	ILI9341_WriteCommand(0x26);
	ILI9341_WriteData(0x01);

	//POSITIVE GAMMA CORRECTION
	ILI9341_WriteCommand(0xE0);
	ILI9341_WriteData(0x0F);
	ILI9341_WriteData(0x31);
	ILI9341_WriteData(0x2B);
	ILI9341_WriteData(0x0C);
	ILI9341_WriteData(0x0E);
	ILI9341_WriteData(0x08);
	ILI9341_WriteData(0x4E);
	ILI9341_WriteData(0xF1);
	ILI9341_WriteData(0x37);
	ILI9341_WriteData(0x07);
	ILI9341_WriteData(0x10);
	ILI9341_WriteData(0x03);
	ILI9341_WriteData(0x0E);
	ILI9341_WriteData(0x09);
	ILI9341_WriteData(0x00);

	//NEGATIVE GAMMA CORRECTION
	ILI9341_WriteCommand(0xE1);
	ILI9341_WriteData(0x00);
	ILI9341_WriteData(0x0E);
	ILI9341_WriteData(0x14);
	ILI9341_WriteData(0x03);
	ILI9341_WriteData(0x11);
	ILI9341_WriteData(0x07);
	ILI9341_WriteData(0x31);
	ILI9341_WriteData(0xC1);
	ILI9341_WriteData(0x48);
	ILI9341_WriteData(0x08);
	ILI9341_WriteData(0x0F);
	ILI9341_WriteData(0x0C);
	ILI9341_WriteData(0x31);
	ILI9341_WriteData(0x36);
	ILI9341_WriteData(0x0F);

	//EXIT SLEEP
	ILI9341_WriteCommand(0x11);
	HAL_Delay(100);

	//TURN ON DISPLAY
	ILI9341_WriteCommand(0x29);

	//STARTING ROTATION
	ILI9341_SetRotation(SCREEN_VERTICAL_1);
}

void ILI9341_SetRotation(uint8_t rotation)
{
	ILI9341_WriteCommand(0x36);
	HAL_Delay(1);

	switch(rotation)
	{
	case SCREEN_VERTICAL_1:
		ILI9341_WriteData(0x40|0x08);
		LCD_WIDTH = 240;
		LCD_HEIGHT = 320;
		break;
	case SCREEN_HORIZONTAL_1:
		ILI9341_WriteData(0x20|0x08);
		LCD_WIDTH  = 320;
		LCD_HEIGHT = 240;
		break;
	case SCREEN_VERTICAL_2:
		ILI9341_WriteData(0x80|0x08);
		LCD_WIDTH  = 240;
		LCD_HEIGHT = 320;
		break;
	case SCREEN_HORIZONTAL_2:
		ILI9341_WriteData(0x40|0x80|0x20|0x08);
		LCD_WIDTH  = 320;
		LCD_HEIGHT = 240;
		break;
	default:
		break;
	}
}

void ILI9341_DrawColor(uint16_t color)
{
	uint8_t buffer[2] = {color>>8, color};
	ILI9341_WriteBuffer(buffer, sizeof(buffer));
}
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

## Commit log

2022-08-31 Added datasheets folder & stm32f303 reference pdf
2022-09-06 added pcb files
    [KBT1.kicad_pcb, KBT1.sch]
2022-09-08 added STM32F091 workspace
    [STM32F0_Test Debugging.cfg]
2022-09-08 removed test workspace
    [STM32F0_Test Debugging.cfg]
2022-09-09 keyboard tester initial work
    [KBT1.kicad_pcb, KBT1.kicad_sch, KBT1.sch]
2022-09-09 added board outline, added missing trace
2022-09-09 increased header size
    [KBT1.kicad_pcb]
2022-09-09 added stm32f407 documentation
2022-09-13 new diode footprint, added mounting holes
    [KBT1.kicad_pcb, KBT1.kicad_sch]
2022-09-13 created gerbers for pcb
    [KBT1-B_Cu.gbr, KBT1-B_Mask.gbr, KBT1-B_Paste.gbr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]
2022-09-13 added stm32f091 documentation
2022-09-15 Created esd protection & Voltage regulation schematics
    [ESD Protection Circuit.kicad_pcb, ESD Protection Circuit.kicad_sch, Input Voltage Regulator.kicad_pcb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]
2022-09-15 Added voltage regulator datasheet
2022-09-16 added stm32f407 errata
2022-09-20 Final project schematic initial commit
    [Splitboard-A.kicad_pcb, Splitboard-A.kicad_sch]
2022-09-23 Added Diode datasheet
2022-09-23 kicad backups
2022-09-27 created 3d model for the keyboard as well as kbt1 acrylic models
    [KBT1 Base Plate.dxf, KBT1 Bottom Plate.dxf, KBT1.step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]
2022-09-27 added note about wiring the keypad
2022-09-27 added workspace for current prototype
2022-09-27 added lcd & stm32 usb documentation
2022-09-28 Keyboard changes (added split to other half, component footprints)
    [Splitboard-A.kicad_pcb, Splitboard-A.kicad_sch, Splitboard-B.kicad_pcb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]
2022-09-29 added pullup resisitors
    [Splitboard-B.kicad_sch]
2022-09-30 started working on I2C
2022-09-30 Schematic modifications
    [Splitboard-A.kicad_sch]
2022-09-30 Schematic changes, linked both boards under a new project
    [Splitboard-A.kicad_sch, Splitboard-B.kicad_sch, Splitboard.kicad_pcb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]
2022-09-30 Schema changes
    [Splitboard-A.kicad_sch, Splitboard-B.kicad_sch, Splitboard.kicad_sch]
2022-09-30 i2c scanning working
2022-09-30 fixed secondary keyboard layout
    [main.c]
2022-10-01 Schema changes (rotary encoder, debug header)
    [Splitboard-B.kicad_sch, Splitboard.kicad_sch]
2022-10-01 added code flowchart
2022-10-02 updated some pins and net labels on sba
    [Splitboard-A.kicad_sch, Splitboard-B.kicad_sch]
2022-10-02 Halved tim6 frequency increased i2c speed to 400kHz
2022-10-03 Layout changes
    [Splitboard-A.kicad_pcb, Splitboard-B.kicad_sch, Splitboard.kicad_sch]
2022-10-04 Side A layout updates
    [Splitboard-A.kicad_pcb]
2022-10-04 keyboard layout changes
    [Splitboard-A.kicad_pcb, Splitboard-A.kicad_sch]
2022-10-04 layout updates
    [Splitboard-A.kicad_pcb, Splitboard-A.kicad_sch]
2022-10-05 Added switch footprint (6x6mm)
    [Splitboard-A.kicad_sch]
2022-10-05 Added Joe's suggestions & notes to schematic & pcb
    [Splitboard-A.kicad_pcb, Splitboard-A.kicad_sch, Splitboard.kicad_sch]
2022-10-06 updated USB, LCD, ESD, Voltage Reg in schematic
    [SOTT323-6L_STM.step, Splitboard-A.kicad_pcb, Splitboard-A.kicad_sch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]
2022-10-06 keypad, i2c, and lcds working together
2022-10-06 assigned new component footprints
    [SOTT323-6L_STM.step, SOT_SiT1630-S_SIT.step, Splitboard-A.kicad_sch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]
2022-10-06 Added debugging header to splitboard B
    [Splitboard-A.kicad_pcb, Splitboard-B.kicad_pcb, Splitboard-B.kicad_sch]
2022-10-06 Splitboard B schematic completed, added some additional notes on board A
    [Splitboard-A.kicad_sch, Splitboard-B.kicad_sch]
2022-10-10 Routing PCB
    [Splitboard-B.kicad_pcb, Splitboard-B.kicad_sch]
2022-10-11 Splitboard A schematic completed (added mosi and sck)
    [Splitboard-A.kicad_sch]
2022-10-13 added more archive files
    [Splitboard-A.kicad_pcb, Splitboard-A.kicad_sch, Splitboard-B.kicad_sch]
2022-10-18 Updated Schematics with suggestions from course staff
    [Splitboard-A.kicad_sch, Splitboard-B.kicad_sch]
2022-10-22 Addes rseries for LCD and added extra vias
    [Splitboard-A-B_Cu.gbr, Splitboard-A-B_Mask.gbr, Splitboard-A-B_Paste.gbr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]
2022-11-11 project for final PCB
2022-11-11 added laser files
    [Side A Bottom.dxf, Side A Top.dxf, Side B Bottom.dxf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]
2022-11-13 row-col scanning working on lab computer and final pcb
    [F407_Final Debug.cfg]
2022-11-14 Started I2c code
2022-11-14 merged logan's I2C changes with my updated layout changes
2022-11-14 cleaned up logic for modifier keys, added primary rotary encoder functionality
2022-11-15 added expander row-col scanning and rotary encoder scanning
2022-11-15 added switch_lcd fix
2022-11-15 fixed undefined keypresses2 errors
    [main.c, main.h]
2022-11-17 row-col scanning w/ entire column issue
    [main.c, main.h]

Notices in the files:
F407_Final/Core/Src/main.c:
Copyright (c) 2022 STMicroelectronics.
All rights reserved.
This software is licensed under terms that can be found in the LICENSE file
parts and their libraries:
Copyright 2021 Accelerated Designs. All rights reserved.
